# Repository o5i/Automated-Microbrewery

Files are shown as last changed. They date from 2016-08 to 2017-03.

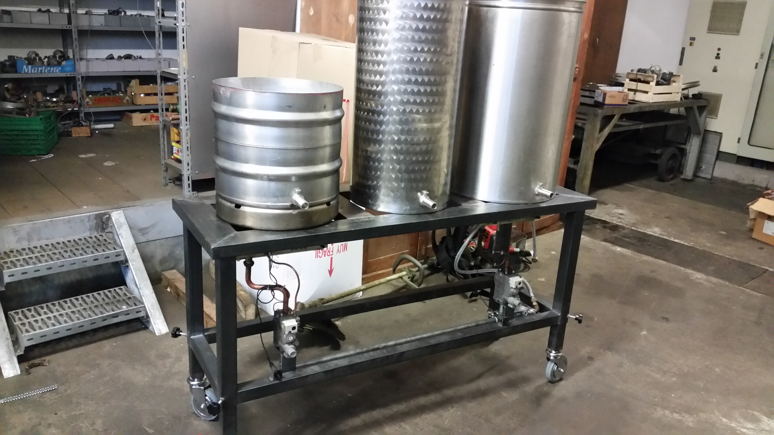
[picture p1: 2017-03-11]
Pics/20160808_192818.jpg

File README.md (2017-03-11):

# Automated-Microbrewery

This is a small hobby/micro brewery based on herms system. i have created for friends.
The setup appart of the work i spend has a good price/quality value. 
In all i spent about 800€ for the hardware.
The controller is made of a raspberry pi (debian linux) interfaced whit a Teensy (Arduino based Microcontroller). 
The program runs on codesys, codesys is a  IEC 61131-3 runtime that allows me to use standard plc programing languages. 
I decided to use the pi because it is possible to interface whit a lot of cheap hardware like the multitouch screen.
The other point is that you have access to the network/internet and you can implement a webinterface or other remote management.
The controller box is made from lasercutted wood.
The gas burners came from old wrecked gas heaters.

Here you can see the controler in action:

https://www.youtube.com/watch?v=9Vse3HxLSbY

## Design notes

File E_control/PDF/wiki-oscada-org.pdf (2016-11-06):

Українська? (http://wiki.oscada.org/HomePageUk/Doc/VCAEngine/edit?add=1)
Русская (http://wiki.oscada.org/Doc/VCAEngine?v=1d1y)

OpenSCADAWiki: Home Page En/ (http://wiki.oscada.org/HomePageEn?v=80q)Doc/VCA (http://wiki.oscada.org/HomePageEn/Doc?v=gns) Engine ... (http://wiki.oscada.org/TextSearch?phrase=HomePageEn%2FDoc%2FVCAEngine)

Home (http://wiki.oscada.org/Home) | Index (http://wiki.oscada.org/PageIndex?v=imj) | Changes (http://wiki.oscada.org/RecentChanges?v=imj) | Comments (http://wiki.oscada.org/RecentlyCommented?v=imj) | Users (http://wiki.oscada.org/Users?v=imj) | Registration (http://wiki.oscada.org/Registration?v=imj) | Login: | Password:

# Module "VCAEngine" of the subsystem "User Interfaces"

Module: | VCAEngine
Name: | Visual control area engine
Type: | User Interfaces
Source: | ui_VCAEngine.so
Version: | 3.7.0
Author: | Roman Savochenko, Maxim Lysenko (2011-2012)
Description: | The main visual control area engine.
License: | GPL

Contents

Introduction

### 1. Purpose 2. The configuration and the formation of interfaces of the VCA 3. Architecture

3.1. Frames and elements of visualization (widgets)
3.2. Project
3.3. Session of the project execution
3.4. Styles
3.5. Events, their processing and the events' maps
3.6. Signaling (Alarms)
3.7. Rights management
3.8. Linkage with the dynamics
3.9. The primitives of the widget Elementary graphic figures (ElFigure)
Element of the form (FormEl)
Text element (Text)
Element of visualization of media materials (Media)
Element of constructing diagrams/trends (Diagram)
Element of building the protocols based on the archives of messages (Protocol) Element of formation of documentation (Document)
Container (Box)
3.10. Database using to store libraries of widgets and projects
3.11. API of the user programming and service interfaces of the OpenSCADA API of the user programming
Service interfaces of OpenSCADA
Access to the values of attributes of the visualization elements (widgets)
Group access to the values of the attributes of the visualization elements (widgets) Access to the pages of the session
Signaling (alarm) management
Manipulation with the sessions of the projects
Group request for the tree of widget libraries

### 4. Configuring the module via the control interface of OpenSCADA

## Introduction

The VCAEngine module provides visual control area engine (VCA) in OpenSCADA system. The module same does not implement the visualization of the VCA, and contains data in accordance with the ideology of "Model/data — Interface". Data visualization of that module is implemented by the visualization modules of VCA, such as Vision (http://wiki.oscada.org/HomePageEn/Doc/Vision?v=1b02) and WebVision. (http://wiki.oscada.org/HomePageEn/Doc/WebVision?v=1e4a)

Visual control area (VCA) is an integral part of the SCADA system. It applies to the client stations with a view to providing accessible information about the object and to for the the issuance of the control actions to the object. In various practical situations and conditions the VCA based on different principles of visualization may by applied. For example, this may be the library of widgets Qt, GTK+, WxWidgets or hypertext mechanisms based technologies HTML, XHTML, XML, CSS, and JavaScript, or third-party applications of visualization, realized in various programming languages Java, Python, etc. Any of these principles has its advantages and disadvantages, the combination of which could become an insurmountable obstacle to the use of VCA in a practical case. For example, technologies like the Qt library can create highly-reactive VCA, which will undoubtedly important for the operator station for control of technological processes (TP). However, the need for installation of that client software in some cases may make using of it impossible. On the other hand, Web-technology does not require installation on client systems and is extremely multi-platform (it is enough to create a link to the Web-server at any Web-browser) that is most important for various engineering and administrative stations, but the responsiveness and reliability of such interfaces is lower that actually eliminates the using of them at the operator of the TP stations.

OpenSCADA system has extremely flexible architecture that allows you to create external interfaces, including user and in any manner and for any taste. For example, the system configuration OpenSCADA as now available as by means of the Qt library, and also the Web-based.

At the same time creation of an independent implementation of the VCA in different basis may cause the inability to use the configuration of one VCA into another one. That is inconvenient and limited from the user side, as well as costly in terms of implementation and follow-up support. In order to avoid these problems, as well as to create as soon as possible the full spectrum of different types of VCA project of the creation of the conception of the VCA (http://wiki.oscada.org/Doc/KoncepcijaSredyVizualizacii?v=ohk) is established. The result of this project — the engine module(data model) of the VCA, as well as direct visualization modules Vision (http://wiki.oscada.org/HomePageEn/Doc/Vision?v=1b02) and WebVision. (http://wiki.oscada.org/HomePageEn/Doc/WebVision?v=1e4a)

## 1. Purpose

This module of the engine (data model) of the VCA is aimed to create the logical structure of the VCA and the execution of sessions of individual instances of the VCA projects. Also, the module provides all the necessary data to the final visualizers of the VCA, both through local mechanisms of interaction of OpenSCADA, and through the management Interface of OpenSCADA for remote access.

The final version of the VCA module will provide:
three levels of complexity in the formation of visualization interface which let organically to develop and apply the tools of the methodology from simple to complex:
1. formation from the template frames through the appointment of the dynamics (without the graphical configuration);

converted by Web2PDFConvert.com

2. graphical formation of new frames through the use of already made visualization elements from the library (mimic panel);
3. formation of new frames, template frames of the visualization elements in the libraries.
building of the visualization interfaces of various complexity, ranging from simple flat interfaces of the monitoring and finishing with the full-fledged hierarchical interface used in SCADA systems;
providing of the different ways of formation and configuration of the user interface, based on different graphical interfaces (Qt, Web, Java ...) and also through the standard management interface of OpenSCADA system;
change of dynamics in the process of execution;
building of the new template frames on the user level and the formation of the frames libraries, specialized for the area of application (eg. the inclusion of frames of parameters, graphs and other items linking them to each other) in accordance with the theory of secondary using and accumulation;
building of the new user elements of the visualization and the formation of the libraries of frames, specialized for the area of application in accordance with the theory of secondary using and accumulation;
description of the logic of new template frames and user visualization elements as with the simple links, and also with the laconic, a full-featured programming language;
the possibility of the inclusion of the functions (or frames of computing of the functions) of the object model of OpenSCADA to the user elements of the visualization, actually linking the presentation of the algorithm of computing (for example, by visualizing the library of models of devices of TP for following visual modeling TP);
separation of user interfaces and interfaces of visualization of data provides building the user interface in a single environment, and performance of it in many others (Qt, Web, Java ...);
the possibility to connect to the performing interface for monitoring and corrective actions (for example, while operator training and control in real time for his actions);
visual building of various schemes with the superposition of the logical links and the subsequent centralized execution in the background (visual construction and performance of mathematical models, logic circuits, relay circuits and other proceedings);
providing of the functions of the object API to the OpenSCADA system, it can be used to control the properties of the visualization interface from the user procedures;
building of the servers of frames, of elements of the visualization and of the project of the interfaces of the visualization with the possibility to serve the set number of the client connections;
simple organization of client stations in different basis (Qt, Web, Java ...) with the connection to the central server;
full mechanism of separation of privileges between the users which allows to create and execute projects with the various rights of access to its components;
adaptive formation of alarms and notifications, with the support of arbitrary ways of notification;
support of the user formation of the palettes and font preferences, into styles, for the visualization of the interfaces;
support of the user formation of maps of the events under the various items of equipment management and user preferences;
support for user profiles, allowing to define various properties of the visualization interface (colors, font characteristics - styles, the preferred maps of events);
flexible storage and distribution of libraries of widgets, frames, and projects of the visualization interfaces in the databases, supported by OpenSCADA; actually users need only to register the database with data.

## 2. The configuration and the formation of interfaces of the VCA

Module itself does not contain mechanisms for visual creating interfaces of VCA, such tools can be given by the final visualization modules of the VCA, for example such a tool provides by the module Vision. (http://wiki.oscada.org/HomePageEn/Doc/Vision?v=1b02)

Although the mechanisms for the visual formation of the VCA the module doesn't provide the interface, implemented on the basis of the management interface of the OpenSCADA, to manage the logical structure is provided, and thus it is available for use in any system configurator of the OpenSCADA. Dialogues of this interface are considered further in the context of the architecture of the module and its data.

## 3. Architecture

/Home Page En / Doc / VC Aconcept / part 4 / part 2 (http://wiki.oscada.org/HomePageEn/Doc/VCAconcept/part4/part2?v=1d34) :: (edit) (http://wiki.oscada.org/HomePageEn/Doc/VCAconcept/part4/part2/edit)

Any VCA can operate in two modes — the development and running. In the development mode the VCA interface and its components are formed, the mechanisms of interaction are identified. While the running it is carried out the formation of VCA interface based on the developed VCA with the final

user interaction is made.

VCA interface is formed of the frames, each of which, in its turn, formed from elements of the primitives, or user interface elements. In doing so, the user interface elements are also formed from the primitives or other user elements. That gives us a hierarchy and reuse of already developed components.

Frames and user elements are placed in the libraries of widgets. The projects of the interfaces of the final visualization of the VCA are formed from these libraries' elements. Based on these projects the visualization sessions are formed.

The structure of VCA is shown in Fig. 3.

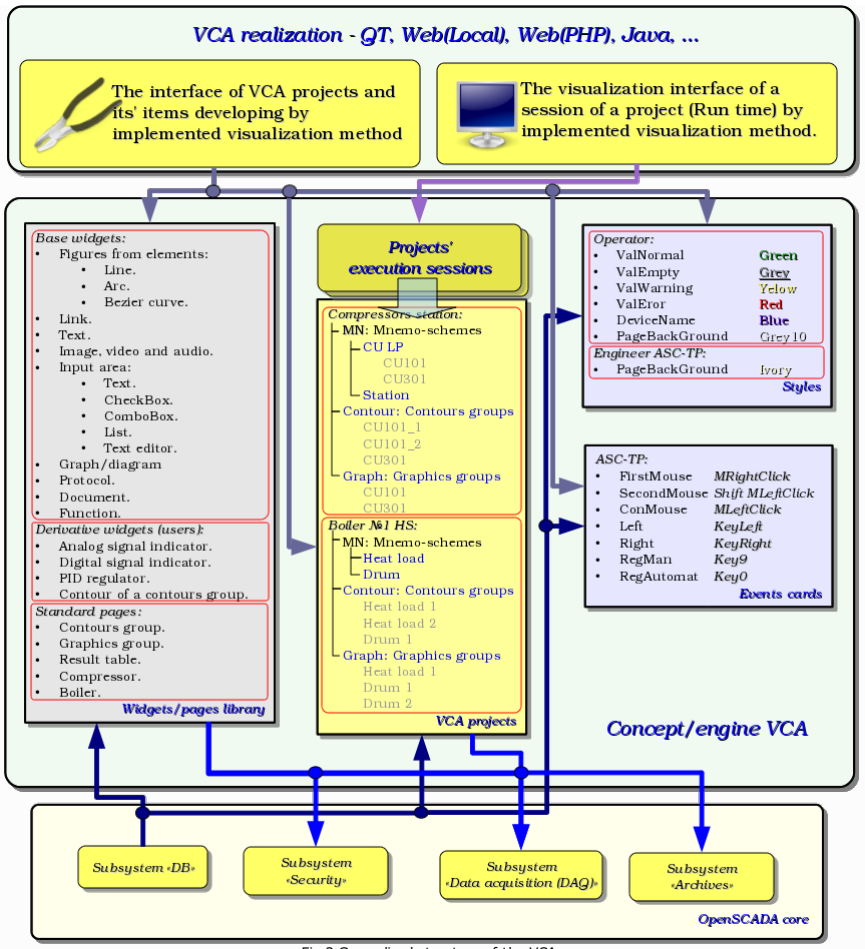
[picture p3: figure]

Fig.3 Generalized structure of the VCA.

This architecture of the VCA allows the support of three levels of complexity of the developing process of the management interface:
Forming of the VC interface (visualization and control) using the library of template frames by placing the templates of the frames in the project and by the assignment of the dynamics.
In addition to the first level the own creation of frames based on the library of derivatives and basic widgets is to be done. Perhaps as a direct appointment of the dynamics in the widget, and the subsequent appointment of it in the project.
In addition to the second level is performed the independently forming of derivatives widgets, new template frames and also the frames with the use of mechanism of describing the logic of interaction and handling of events in one of the languages of a user programming of OpenSCADA system.
/Home Page En / Doc / VC Aconcept / part 4 / part 2 (http://wiki.oscada.org/HomePageEn/Doc/VCAconcept/part4/part2?v=1d34) :: (edit) (http://wiki.oscada.org/HomePageEn/Doc/VCAconcept/part4/part2/edit)

## 3.1. Frames and elements of visualization (widgets)

/Home Page En / Doc / VC Aconcept / part 4 / part 3 (http://wiki.oscada.org/HomePageEn/Doc/VCAconcept/part4/part3?v=k3m) :: (edit) (http://wiki.oscada.org/HomePageEn/Doc/VCAconcept/part4/part3/edit)
Frame is the window which directly provides information to the user in a graphical or text form. The group of interconnected frames creates whole user interface of VC.

Contents of the frame is forming from the elements of visualization (widgets). Widgets may be the basic primitives (different elementary shapes, text, trend, etc.) and derivatives (formed from the basic or other derivatives of widgets). All the widgets are grouped into the libraries. In the process, you can build your own library of derivative widgets.

Actually the frame is also a widget that is used as a final element of visualization. This means that the widget libraries can store the blanks of frames and the templates of the resulting pages of the user interface.

Frames and widgets are passive elements that do not normally contain links to the dynamics and other frames, but only provide information about the properties of the widget and the nature of the dynamics (configuration), connected to the properties of the frame. Activated frames, ie containing links to the dynamics and active connections, form the user interface and are stored in the projects. In some cases, it is possible the direct appointment of the dynamics in the blanks of frames.

Derivative frames/widgets can contain other widgets (attached), which can be glued (associated) with the logic of one another by one of the languages of programming available in the OpenSCADA system.

The widget is an element, by means of which it is provided:
visualization of operational and archive information about TP;
alarm about a violation of conduction of TP;
switching between the frames of TP; management of technological equipment and the parameters of conduction of TP.

Tuning and linkage of the widgets is done through their properties. Parent widget and the widgets it contains, can be complemented by user properties. Then the user and static attributes are associated with the properties of embedded widget by internal logic. To show the dynamics (ie, current and archived data), properties of widgets are dynamized, that is linked with the attributes of the parameters of OpenSCADA or properties of other widgets. Using to link of the nested widgets by means of the internal logic with the available programming language of the OpenSCADA system eliminates the question of the implementation of complex logic of visualization, thus providing high flexibility. Practically, you can create fully dynamized frames with complex interactions at the level of the user.
/Home Page En / Doc / VC Aconcept / part 4 / part 3 (http://wiki.oscada.org/HomePageEn/Doc/VCAconcept/part4/part3?v=k3m) :: (edit) (http://wiki.oscada.org/HomePageEn/Doc/VCAconcept/part4/part3/edit)

## 3.2. Project

/Home Page En / Doc / VC Aconcept / part 4 / part 4 (http://wiki.oscada.org/HomePageEn/Doc/VCAconcept/part4/part4?v=oor) :: (edit) (http://wiki.oscada.org/HomePageEn/Doc/VCAconcept/part4/part4/edit)
Direct configuration and properties of the final visualization interface are contained in the project of the visualization interface of the VCA, which may be created lot ones.

Each project includes pages from the libraries of the frames/widgets. In some modes the page allowed to include into nested pages as independent from the parent and in using the parent as template. The template's page-widget allows to extremely simplify the process of creating the same type of the frames by the ACS-TP engineer or by the user of OpenSCADA for easy monitoring. An example of such one-type frames may be: groups of contours, groups of graphs, reports and various tables. Mnemonic schemes of technological processes rarely come under this scheme and will be formed directly in the description of the frame.

Page like to a widget on which it is based provides a possibility for bind the dynamics to described into properties, which links at all can be set to dynamic or resolved as constants. Besides, links to the dynamics on the project's page level is preferable to the widget of libraries level.

Example of hierarchical representations of components of the project of the classical interface of VC of the technological process with the description of standard call expressions is given in Figure.

Reserved next the special properties of pages:
Container — page is a container for the underlying pages.
Template — page is a template for the underlying pages.
Empty — empty and inactive page. This property is used in conjunction with the property Container for logical containers organization.

Based on these properties combinations the following types of pages are realized:
Standard — the standard page (none property is set), it is the full final page.
Container — the full-featured page with the property of the container (Container).
Logical container — the logical container is actually not a page (Container|Empty), but it performs property of the intermediate and bunching element in the tree of pages.
Template — the template page (Template). Pure template page is used to describe the common properties and expand them definitions in privately order in nested pages.
Container and template — the template and a container page (Template|Container), combines the functions of the template and the container.

On the side of the visualization (RunTime), on the following attributes of the basic element "Box", there is the logic regulating how to open the pages: pgOpen — sign "The page is opened";
pgNoOpenProc — sign "Execute the page, even if it is not opened";
pgOpenSrc — contains the address of the widget or of the page which has opened the current; in the case of the nested container widget here it is contained the address of the included page; to open the pages from the script here it is enough to indicate the address of the widget-source of the opening;
pgGrp — group of pages, used for conjunction of the containers of the pages with the pages in accordance with the general group.

The logic of the method of the opening the pages works in the following way:
if the page has the group "main" or coincides with a group of the page in the main window or there is no page on the main window, then open the page in the main window;
if the page has a group which coincides with the group one of the containers of the current page, then open it in the container;
if the source of the opening of the page coincides with the current page, then open it as an additional window over the current page;
transmit a call for request for the opening to the additional windows with the processing in each of the first three paragraphs;
if any one of the relative windows doesn't open a new page, then open it as a related window of the main window.
/Home Page En / Doc / VC Aconcept / part 4 / part 4 (http://wiki.oscada.org/HomePageEn/Doc/VCAconcept/part4/part4?v=oor) :: (edit) (http://wiki.oscada.org/HomePageEn/Doc/VCAconcept/part4/part4/edit)

## 3.3. Session of the project execution

/Home Page En / Doc / VC Aconcept / part 4 / part 5 (http://wiki.oscada.org/HomePageEn/Doc/VCAconcept/part4/part5?v=5ox) :: (edit) (http://wiki.oscada.org/HomePageEn/Doc/VCAconcept/part4/part5/edit)
The project's session is expanded tree of the project for direct it execution, which includes an individual task of hierarchical the widget's procedures execution. For each project can be opened many sessions. The end-user visual interface forming performs by the visualizers from data of the project's session, after the session creation by the request.

Between widgets at the different levels of hierarchy complex inheritance relations are arranged, which are defined by the possibility of using some widgets by other ones, beginning with the library widget, and finishing with the widget to the session. To clarify these features of the interaction in Figure comprehensive map of "uses" inheritance is shown.

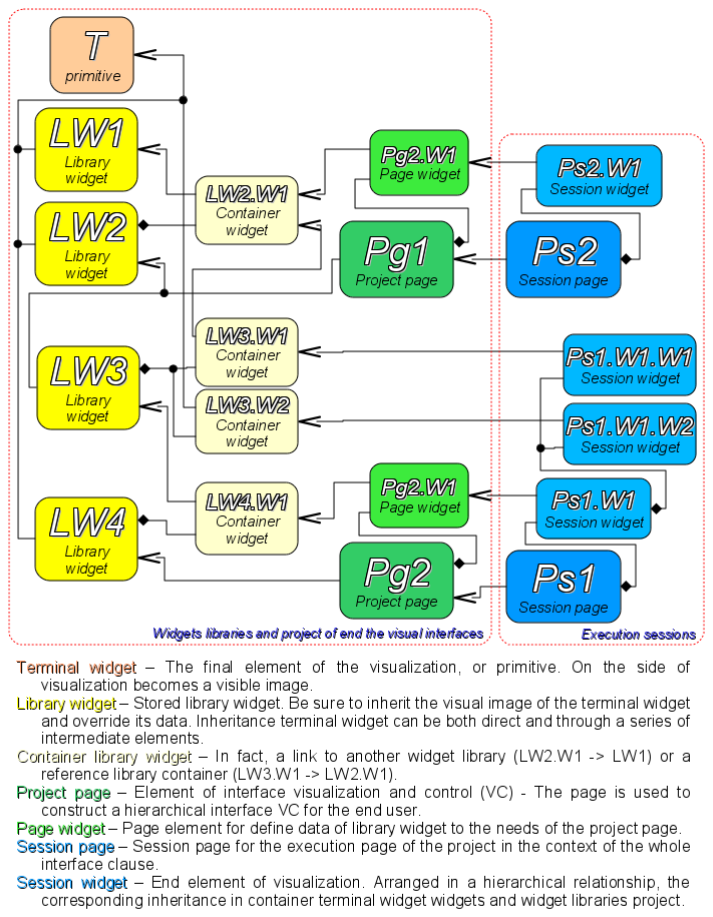
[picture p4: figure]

At the session level widget contains a object of values of calculation procedure. This object is initiated and used in the case of presence of the calculation procedure. At the time of the initialization the list of parameters of the procedure is created and a compilation of procedure is performed with these parameters in the module, implementing the selected programming language and encoded with the full name of the widget. A compiled function is connected to the object of values of the calculation procedure. Further the calculation is performed with the frequency of the session.

Calculation and processing of the widget on the whole runs in the following sequence:
the events, which are available at the time of computation, are selected from the attribute "event" of the widget;
events are loaded into the parameter "event" of the object of computation;
values of the input connections are loaded into the object of calculation;
values of special variables are loaded into the computation object (f_frq, f_start and f_stop);
values of selected parameters of the widget are loaded into the object of computation; computation;
uploading of the computation object's values to the selected parameters of the widget; uploading of the event from the parameter "event" of the computation object;
processing the events and transfer the unprocessed events at the level above.

The objects of the session of the project inherit from an abstract object "Widget" and use the appropriate objects of the project. Thus, the session ("Session") uses the project ("Project") and forms expand tree on its basis. Project page "Page" is directly used by the session page "SessPage". The remaining objects ("SessWdg") are deployed in accordance with the hierarchy of page elements (Fig.3.1.2).

In addition to the standard properties of an abstract widget ("Widget") elements of the pages of session themselves get the following properties: (http://www.web2pdfconvert.com?ref=PDF)

storage of the object of values of computational procedure, calculation of the procedures and mechanism for processing of the events. Pages of the session, in addition, contain a container of the following by the hierarchy pages. The session generally is computed with the frequency and in the consistency:
"Page of the top level" -> "Page of the lower level"
"Widget of the lower level" -> "Widget of the top level"

This policy allows you to circumvention the pages in accordance with the hierarchy, and to rise on the top during the one iteration for the widget events.
/Home Page En / Doc / VC Aconcept / part 4 / part 5 (http://wiki.oscada.org/HomePageEn/Doc/VCAconcept/part4/part5?v=5ox) :: (edit) (http://wiki.oscada.org/HomePageEn/Doc/VCAconcept/part4/part5/edit)

## 3.4. Styles

/Home Page En / Doc / VC Aconcept / part 4 / part 6 (http://wiki.oscada.org/HomePageEn/Doc/VCAconcept/part4/part6?v=6si) :: (edit) (http://wiki.oscada.org/HomePageEn/Doc/VCAconcept/part4/part6/edit)
It knows that people can have individual characteristics in the perception of graphical information. If these features are not taken into account, it is possible to obtain the rejection and abruption of the user to the interface of VC. This rejection and abruption can lead to fatal errors in the management of TP, as well as traumatize the human by the continuous work with the interface. In SCADA systems the agreements are adopted, which regulate the requirements for creating a unified interface of VC normally perceived by most people. This is practically eliminates the features of people with some deviations.

In order to take this into account and allow centralized and easy to change the visual properties of the interface module is implementing a theme manager of the visualization interface.

User can create many themes, each of which will keep the color, font and other properties of the elements of the frame. Simple changing of the theme will allow you to change the interface of VC, and the possibility of appointing an individual theme in the user's profile allows to take into account his individual characteristics.

To realize this opportunity, when you create a frame, it is necessary for the properties of color, font and others set the "Config" (of the table in the "Process" tab) in the value of "From style". And in the parameter "Config template" to specify the identifier of the style field. Further, this field will automatically appear in the Style Manager and will be there to change. Style Manager is available on the project configuration page in the tab "Styles". On this tab you can create new styles, delete old ones, change the field of the style and delete unnecessary.

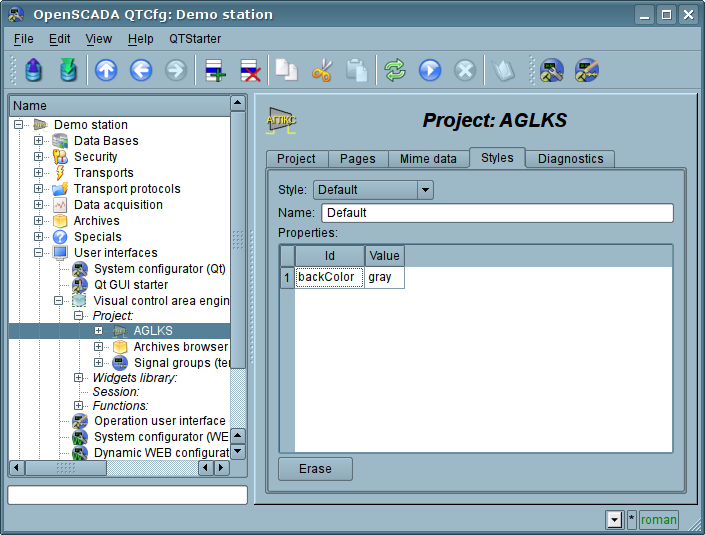
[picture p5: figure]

Figure. "Styles" tab of the configuration page of the project.

In general the styles are available from the project level. At the level of libraries of widgets you can only define styles fields of widgets. At the project level, at the choice of style, it is started the work with styles, which includes access to the fields of styles instead of direct attribute values. In fact, this means that when reading or writing a widget attribute these operations will be carried out with the corresponding field of the chosen style.

When you run the project execution it will be used the set in the project style. Subsequently, the user can select a style from the list of available ones. The user's style will be saved and used next time you run the project.
/Home Page En / Doc / VC Aconcept / part 4 / part 6 (http://wiki.oscada.org/HomePageEn/Doc/VCAconcept/part4/part6?v=6si) :: (edit) (http://wiki.oscada.org/HomePageEn/Doc/VCAconcept/part4/part6/edit)

## 3.5. Events, their processing and the events' maps

/Home Page En / Doc / VC Aconcept / part 4 / part 7 (http://wiki.oscada.org/HomePageEn/Doc/VCAconcept/part4/part7?v=12be) :: (edit) (http://wiki.oscada.org/HomePageEn/Doc/VCAconcept/part4/part7/edit)
Given the range of tasks for which the OpenSCADA system may be used, it is necessary to provide a tool for management of interactive user events. This is due to the fact that in dealing with individual tasks of embedded systems, input and control devices can greatly vary. But it is enough to look at the regular office keyboard and notebook one, that would remove any doubt about the necessity for the manager of events.

The events manager must work using the maps of events. Map of the events — is the list of named events, indicating their origin. The origin of the events can be a keyboard, mouse, paddle, joystick, etc. At an event emerge the events manager is looking for it in the active map and compares with the name of the event. A comparison name of the event is placed in the queue for processing. Widgets in this case must process the given queue of events.

The active map of events is specified in the profile of each user or it is set by default (in planes).

In general, four types of events are provided:
events of the shapes-primitives of VCA (prefix: ws_), for example, pressing of the display button event — "ws_BtPress"; keyboard events (prefix: key_) — all events from mouse and keyboard in the form of — "key_presAlt1";

user events (prefix: usr_) are generated by the user in the procedures of the calculation of widgets; mapping of the event (prefix: map_) — events from the map of events, in planes.

Event itself represents deficiently information, especially if its processing occurs at higher level. For the unequivocal identification of the event and its source in the whole the event is recorded as follows: "ws_BtPress:/curtime". Where:
ws_BtPress — same event;
/curtime — the path to the child element that has generated the event.

Table 3.5 provides a list of standard events, the support of which should be provided in visualizers of VCA.

Table 3.5. Standard events
Id | Description

Keyboard events: key_[pres|rels][Ctrl|Alt|Shift]{Key}

*SC#3b | Scan-code of the key.
*#2cd5 | Code of the unnamed key.
*Esc | "Esc".
*BackSpace | Removing of the previous character — "<--".
*Return, *Enter | Enter — "Enter".
*Insert | Insertion — "Insert".
*Delete | Deleting — "Delete".
*Pause | Pause — "Pause".
*Print | Print of the screen — "Print Screen".
*Home | Home — "Home".
*End | End — "End".
*Left | Left — "<-".
*Up | Up — '^'.
*Right | Right — "->".
*Down | Down — '\/'.
*PageUp | Page up — "PageUp".
*PageDown | Page down — "PageDown".
*F1 ... *F35 | Function key from "F1" to "F35".
*Space | Space — ' '.
*Apostrophe | Apostrophe — '`'.
*Asterisk | Asterisk on an additional field of the keyboard — '*'.
*Plus | Plus on an additional field of the keyboard — '+'.
*Comma | Comma — ','.
*Minus | Minus — '-'.
*Period | Period — '.'.
*Slash | Slash — '\'.
*0 ... *9 | Number from '0' to '9'.
*Semicolon | Semicolon — ';'.
*Equal | Equal — '='.
*A ... *Z | Keys of Latin alphabet from 'A' to 'Z'.
*BracketLeft | Left square bracket - '['.
*BackSlash | Backslash — '/'.
*BracketRight | Right square bracket — ']'.
*QuoteLeft | Left quote — '''.

Keyboard focus events.

ws_FocusIn | Focus is obtained by a widget.
ws_FocusOut | Focus is lost by a widget.

Mouse events:

key_mouse[Pres|Rels][Left|Right|Midle] | Pressed/released the mouse button.
key_mouseDblClick | Double-click the left mouse button.

Events of quittance on the side of the visualizer.

ws_alarmLev | Quittance of all violations by all notices methods and types.
ws_alarmNtf{N} | Quittance of all violations by the type {N} (0...7).

Events of the primitive of elemental figure ElFigure:

ws_Fig[Left|Right|Midle|DblClick] | Activating of the figures (fills) by the mouse button.
ws_Fig{N}[Left|Right|Midle|DblClick] | Activating of the figure (fill) N by the mouse button.

Events of the primitive of form elements FormEl:

ws_LnAccept | A new value in the input line is set.
ws_TxtAccept | The value of the text editor is changed.
ws_ChkChange | The state of the flag is changed.

ws_BtPress | The button is pressed.
ws_BtRelease | The button is released.
ws_BtToggleChange | The button toggle is changed.
ws_BtMenu={Item} | Selection of the menu Item.
ws_BtLoad | The selected file loaded.
ws_CombChange | The value of the combo box is changed.
ws_ListChange | The current list item is changed.
ws_TreeChange | The current tree item is changed.
ws_TableChangeSel | The table's item selection changed.
ws_TableEdit_{colN}_{rowN} | The table's cell ({colN}:{rowN}) edited.
ws_SliderChange | The slider position changed.

Events of the primitive of media content Media:

ws_MapAct{N}[Left|Right|Midle] | Media area with the number N is activated by the mouse button.
ws_MediaFinished | Media-stream play is finished.

Events are the main mechanism of notification and is actively used for user interaction. For the event processing there are two mechanisms: Primary — the script uses to control the opening of the pages.
Secondary — the computational procedure of the widget.

The mechanism "Scripts for the control the opening of pages" based on the basic attribute of the widget "evProc", which can be used for switching, opening, substitution and navigation through the pages. The scenario of this attribute is stored as a list of commands with the syntax: "{event}: {evSrc}:{com}:{prm}". Where:
event — the expected event;
evSrc — the path of the nested widget-source of the event;
com — the session command;
prm — the parameter of the command.

The following commands are implemented:
open — opening page; page to open is specified in the parameter prm both in direct way and as a template (example: /pg_so/1/*/*); next — opening of the next page; page to open is specified in the parameter prm as a template (example: /pg_so/*/*/$);
prev — opening of the previous page; page to open is specified in the parameter prm as a template (example: /pg_so/*/*/$).

Special characters of the template are deciphered as follows:
pg_so — direct name of the desired-static page (with the prefix), requires the compulsory accordance and is used to identify the last open page; 1 — name of a new page in a general way (without a prefix);
* — the page is taken from the name of a previous opened page or the first available page is substituted, if the previous opened page is missing; $ — points the place of the opened page relative to which you are to go to the next or to the previous one.

To more and true the mechanism of the templates understanding lets cite some real examples:
Changing the signal object:
Initially: /pg_so/pg_1/pg_mn/pg_1 Command: open:/pg_so/2/*/* Result: /pg_so/pg_2/pg_mn/pg_1 Switching of the type:
Initially: /pg_so/pg_1/pg_mn/pg_1 Command: open:/pg_so/*/gkadr/* Result: /pg_so/pg_1/pg_gkadr/pg_1 Next/previous page of the type: Initially: /pg_so/pg_1/pg_mn/pg_1 Command: next:/pg_so/*/*/$ Result: /pg_so/pg_1/pg_mn/pg_2

As an example lets cite the scenario of operation of the main page of the user interface:

ws_BtPress:/prev:prev:/pg_so/*/*/$
ws_BtPress:/next:next:/pg_so/*/*/$
ws_BtPress:/go_mn:open:/pg_so/*/mn/* ws_BtPress:/go_graph:open:/pg_so/*/ggraph/* ws_BtPress:/go_cadr:open:/pg_so/*/gcadr/* ws_BtPress:/go_view:open:/pg_so/*/gview/* ws_BtPress:/go_doc:open:/pg_so/*/doc/* ws_BtPress:/go_resg:open:/pg_so/rg/rg/* ws_BtPress:/so1:open:/pg_so/1/*/* ws_BtPress:/so2:open:/pg_so/2/*/* ws_BtPress:/so3:open:/pg_so/3/*/* ws_BtPress:/so4:open:/pg_so/4/*/* ws_BtPress:/so5:open:/pg_so/5/*/* ws_BtPress:/so6:open:/pg_so/6/*/* ws_BtPress:/so7:open:/pg_so/7/*/* ws_BtPress:/so8:open:/pg_so/8/*/* ws_BtPress:/so9:open:/pg_so/9/*/* ws_BtPress:*:open:/pg_control/pg_terminator

The mechanism "Processing the events with the help of computational procedure of the widget" is based on the attribute "event" and the user procedure of calculating written with the help of the programming language of OpenSCADA. The events, in process of receipt, are accumulated in the attribute "event" till the moment of call of the computational procedure. The computational procedure is called with the specified frequency of calculating the widget and receives a value for the attribute "event" as the list of events. In the calculation procedure the user can: analyze, process and delete the processed events from the list, and add to the list new events. The remaining, after the procedure execution, and new events are analyzed for compliance with the conditions of the call by means of script of the primary mechanism, after which the remaining events are transmitted to the upper by the hierarchy widget to be processed by it, with the correction of the path of events in accordance with the hierarchy of the penetration of the event.

The content of the attribute "event" is a list of events in the format "{event}:{evSrc}", with the event on the separate line. Here is an example of (http://www.web2pdfconvert.com?ref=PDF) processing events in the Java-like programming language of the OpenSCADA:

for(ev_rez = "", off = 0; (sval=event.parse(0,"\n",off)).length; ) { if(sval == "ws_BtPress:/cvt_light") alarmSt = 0x1000001;
else if(sval == "ws_BtPress:/cvt_alarm") alarmSt = 0x1000002; else if(sval == "ws_BtPress:/cvt_sound") alarmSt = 0x1000004; else ev_rez += sval+"\n";
}
event = ev_rez;

/Home Page En / Doc / VC Aconcept / part 4 / part 7 (http://wiki.oscada.org/HomePageEn/Doc/VCAconcept/part4/part7?v=12be) :: (edit) (http://wiki.oscada.org/HomePageEn/Doc/VCAconcept/part4/part7/edit)

## 3.6. Signaling (Alarms)

/Home Page En / Doc / VC Aconcept / part 4 / part 8 (http://wiki.oscada.org/HomePageEn/Doc/VCAconcept/part4/part8?v=klz) :: (edit) (http://wiki.oscada.org/HomePageEn/Doc/VCAconcept/part4/part8/edit)
An important element of any visualization interface is the user notification about the violation — alarming. To simplify the perception, but also in mind the close connectivity of visualization and notification (typically notification is amplified with the visualization) it is decided to integrate the interface of a notification in the visualization interface. To do this, all the widget provides two additional attributes (of the session level): "alarm" and "alarmSt". Attribute "alarm" is used to form the signal by the widget, according to his logic, and attribute "alarmSt" is used to control the signaling fact of the branch of the tree of the session of the project.

Attribute "alarm" is a line and has the following format: "{lev}|{categ}|{message}|{type}|{tp_arg}" Where:

lev — signaling (alarm) level; number from 0 to 255;
categ — alarm category; parameter of the acquisition subsystem, object, path, or their combination; message — signaling (alarm) message;

type — type of notification, is formed as a the integer number (0...7), which contains the flags of notification methods; typical notification methods:

1 — visual;
2 — beep tone, is frequently made through the PC-speaker;
4 — sound signal from the sound file or the speech synthesis, and if in the tp_arg the name of the resource of the sound file is specified, then play it, or in other case the speech synthesis from the text specified in message is made.
tp_arg — argument of the type; it is used in the case of the audible signal to indicate the resource of the sound alarm (file of the sound format).

Attribute "alarmSt" is an integer number that represents the maximum alarm level and the fact of the quittance of the branch of the tree of the session of the project. Format of the number is as follows:
first bite (0...255) characterizes the level of the alarm of the branch;
the second byte indicates the type of notification (as well as in the attribute "alarm");
the third byte indicates the type of notification without quittance (as well as in the attribute "alarm"); the four byte has special appointment, assigns different bites
bit 0 — indicates, by sets, to quittance fact of notification into first byte;
bit 1 — indicates, by sets it and the bit 0, to the quittance return — enable back the quittance.

Alarm formation and receipt of it by the visualizer.
The alarm formation is performed by the widget by setting its own attribute "alarm" in appropriate way and in accordance with it the attribute "alarmSt" of current and the parent widget is set. Visualizers receive notification of the alarm using a standard mechanism for notifications of the changes of attributes of widgets.

Taking into account that the processing of conditions of the signaling is made in the widgets, the pages containing the objects of signaling should be performed in the background, regardless of their openness to the moment. This is done by setting a flag of the background execution of the page.

Although the mechanism of signaling is built in the visualization area the possibility of formation of visual signaling elements remains, for example by creating the page that will never be opened.

Quittance
Quittance is process of accepting the violation(s) to mind, disabling the notification and action to remove the violation(s). In the display of user's interface the quittance assume only the notification disable.

Quittance performs by specifying the root of the branch of the widgets and the types of notification. This allows to make quittance on the side of visualizer both as by groups, for example by the signaling objects as well as individually by the objects. It is possible to independently quittance different types of alarms. Setting of the quittance is made by the simple modification of the attribute "alarmSt".

Example of the script to work with the signals gives below:

//Secretion of the existence of alarms for different ways of notification
cvt_light_en = alarmSt&0x100; cvt_alarm_en = alarmSt&0x200; cvt_sound_en = alarmSt&0x400; //Secretion of the existence of alarms which not in quittance for different ways notification cvt_light_active = alarmSt&0x10000; cvt_alarm_active = alarmSt&0x20000; cvt_sound_active = alarmSt&0x40000;
//Processing of the button's events of quittance and the quittance for different ways of notification
for(ev_rez = "", off = 0; (sval=event.parse(0,"\n",off)).length; ) {
if(sval == "ws_BtPress:/cvt_light") alarmSt = 0x1000001;
else if(sval == "ws_BtPress:/cvt_alarm") alarmSt = 0x1000002; else if(sval == "ws_BtPress:/cvt_sound") alarmSt = 0x1000004; else ev_rez += sval + "\n";
}

External notification methods
A first and a typical method of notifications is display's light notification by alarm colors and its dynamic about proper visual elements, which always presents and does not require of specific configuration. But often we need for an external type notification, for example: external lamp, PC buzzer or "howler", arbitrary sound, synthesized speech and etc.

For the possibility of implements the external notification methods and the accorded notification types are free described for the visualization server and same visualizers. On the visualization server side describes for forming/getting the notification resource and same notification. On the visualizers side describes a notification by the resources from the visualization server.

The external notifications describes on main page by attributes of text type:

Description of rules and scenarios of notifications performs with user attributes of text type for pages of the visualization project, which applies at the page open. That is potentially for each opening page there possible describe self rules of notifications but typically here enough to describe a generic (http://www.web2pdfconvert.com?ref=PDF) rules of notification on the main project's page, which open once and doesn't close in work:

For the visualization server/engine by the attribute "notify{N}" into the format:

//flags=notify[{DL}][|resource[|queue[|qMergeMess]]];
if(doRes) { The command text to form the resource. }
if(doNtf) { The command text to notify. }

For a visualizer by the attribute "notifyVis[Vision|WebVision]{N}" into the format:

//flags=notify[{DL}][|resource[|queue[|quittanceRet]]]; //name={The notifier name}
//ico={The icon name}
{ The notification command text to any or concrete visualizer. }

Flags:
notify[{DL}] — enables notification with repeat by time DL, if the set; for DL = 0 the repeat made once.
resource — request-form (force) the notification resource from the visualization server, can be an audio file, a text or other data for the notification produce.
queue — the notification resources appoint not only by global alarming sign and the quittance but follow to the priority queue of sources of the notification-resources. The queue forms on the visualization server side and for the visualizers set need of working with it at the resources request.
qMergeMess — merging the notifications into the queue by equality its messages.
quittanceRet — possibility of a visualizer for a quittance recall-return ie in fact the notification enable back.

The exchanging variables:
en[0,1] — the notification enable (1) or disable (0);
doNtf[0,1] — call the script for the notification;
doRes[0,1] — call the script for the resource form;
res — the content or the content's file name (for external scripts) of the resource; mess — the message-parameters for the resource and the notification form.

lang — the language of current user or system.

The examples and comments to work of typical notification methods: Beep (buzzer) on a visualizer or the visualization server side: alarm = "10|Prm||0x02"
notifyVisVision1 | notify1 =

//flags=notify
if(en) SYS.system("beep -f 1000 -l 1000000 &", true);
else if((beepPID=SYS.system("pidof beep")).toInt()) SYS.system("kill "+beepPID);
notifyVisVision1 | notify1 =

#!/bin/sh

#flags=notify

if test $en = 1; then
beep -f 1000 -l 1000000 &
else
beepPID=$(pidof beep)
if test "x$beepPID" != "x"; then kill $beepPID; fi fi

Repeating play for ready audio file, one common, on a visualizer or the visualization server side: alarm = "10|Prm||0x04"
notify2 | notifyVisVision2 =

//flags=notify2
if(en) SYS.system("play -q alarm.ogg");
notify2 | notifyVisVision2 =

#!/bin/sh

#flags=notify2

if test $en = 1; then play -q alarm.ogg; fi

Play an individual audio file for the source, on the visualization server side: alarm = "10|Prm||0x04|res:al_prm1"
notify2 =

//flags=queue

notifyVisVision2 =

//flags=notify2|queue
if(doNtf && en && res.length) { SYS.fileWrite("tmpPlay", res); SYS.system("play -q tmpPlay"); SYS.fileRemove("tmpPlay");
}

notifyVisVision2 =

#!/bin/sh

#flags=notify2|queue

if test $doNtf = 1 -a $en = 1 -a -s $res; then play -q $res; fi

Speech synth for an individual message for the source, on a visualizer side:
alarm = "10|Prm|Text message for the speech synth|0x04"
notify2 =

//flags=queue

notifyVisVision2 =

//flags=notify2|queue
if(doNtf && en && mess.length) { SYS.fileWrite("tmpForSpeech", mess); SYS.system("festival --tts tmpForSpeech"); SYS.fileRemove("tmpForSpeech");
}

notifyVisVision2 =

#!/bin/sh

#flags=notify2|queue

if test $doNtf = 1 -a $en = 1 -a "x" != "x$mess"; then echo $mess > tmpForSpeech
festival --tts tmpForSpeech
rm tmpForSpeech
fi

Once audio file prepare and playing that on a visualizer or the visualization server side:

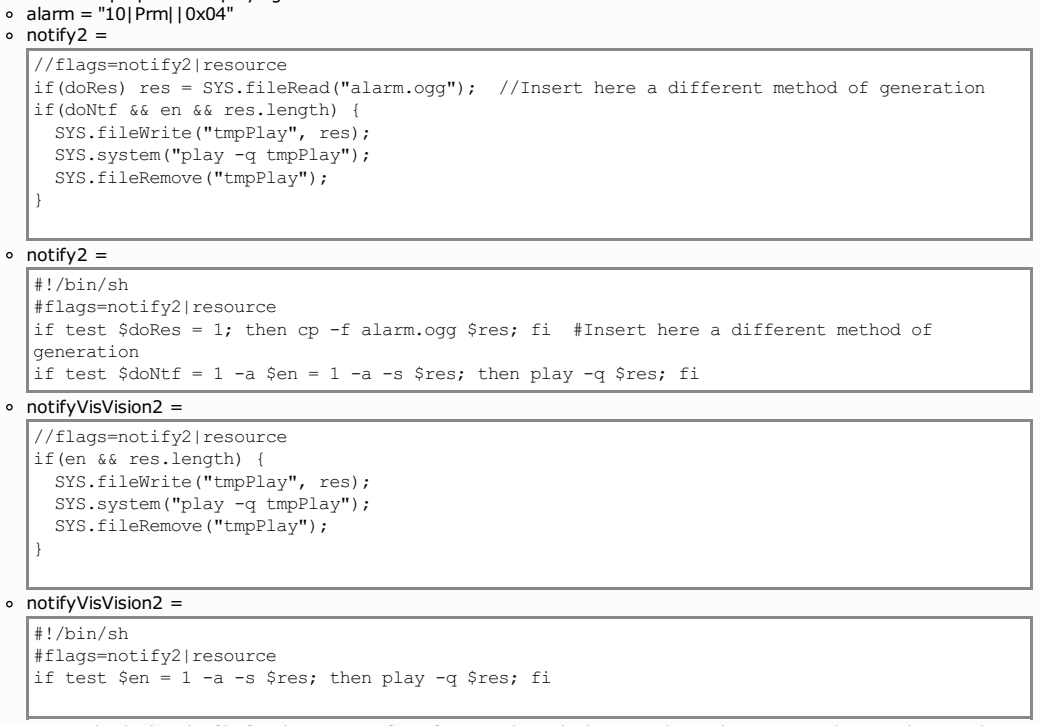
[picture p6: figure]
alarm = "10|Prm||0x04" notify2 =; //flags=notify2|resource; if(doNtf && en && res.length) { SYS.fileWrite("tmpPlay", res);; SYS.system("play -q tmpPlay"); SYS.fileRemove("tmpPlay");; notify2 =; #!/bin/sh; #flags=notify2|resource; generation; notifyVisVision2 =; if(en && res.length) { SYS.fileWrite("tmpPlay", res);

if(doRes) res = SYS.fileRead("alarm.ogg"); | //Insert here a different method of generation
if test $doRes = 1; then cp -f alarm.ogg $res; fi | #Insert here a different method of

if test $doNtf = 1 -a $en = 1 -a -s $res; then play -q $res; fi

if test $en = 1 -a -s $res; then play -q $res; fi

Prepare an individual audio file for the source of notification through the speech synth, on a visualizer or the visualization server side: alarm = "10|Prm|Text message for the speech synth|0x04"

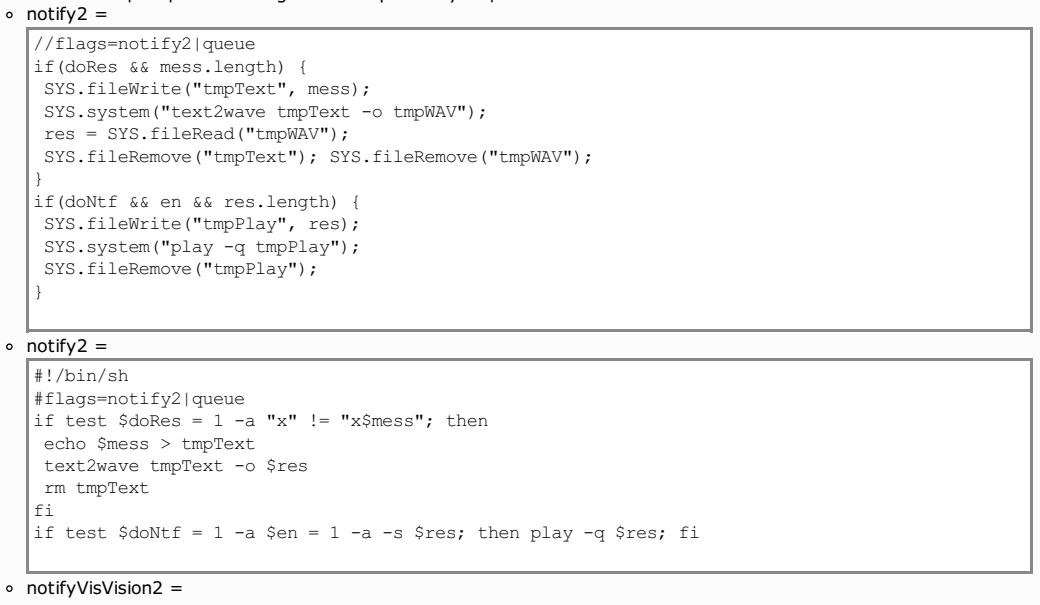
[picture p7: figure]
notify2 =; //flags=notify2|queue; if(doRes && mess.length) { SYS.fileWrite("tmpText", mess);; res = SYS.fileRead("tmpWAV");; } if(doNtf && en && res.length) { SYS.fileWrite("tmpPlay", res);; SYS.system("play -q tmpPlay"); SYS.fileRemove("tmpPlay");; #!/bin/sh; #flags=notify2|queue; echo $mess > tmpText text2wave tmpText -o $res; rm tmpText fi; notifyVisVision2 =

SYS.system("text2wave tmpText -o tmpWAV");

SYS.fileRemove("tmpText"); SYS.fileRemove("tmpWAV");

if test $doRes = 1 -a "x" != "x$mess"; then

if test $doNtf = 1 -a $en = 1 -a -s $res; then play -q $res; fi

//flags=notify2|queue
if(en && res.length) {
SYS.fileWrite("tmpPlay", res); SYS.system("play -q tmpPlay"); SYS.fileRemove("tmpPlay");
}

notifyVisVision2 =

#!/bin/sh

#flags=notify2|queue

if test $en = 1 -a -s $res; then play -q $res; fi

/Home Page En / Doc / VC Aconcept / part 4 / part 8 (http://wiki.oscada.org/HomePageEn/Doc/VCAconcept/part4/part8?v=klz) :: (edit) (http://wiki.oscada.org/HomePageEn/Doc/VCAconcept/part4/part8/edit)

## 3.7. Rights management

/Home Page En / Doc / VC Aconcept / part 4 / part 9 (http://wiki.oscada.org/HomePageEn/Doc/VCAconcept/part4/part9?v=ebr) :: (edit) (http://wiki.oscada.org/HomePageEn/Doc/VCAconcept/part4/part9/edit)
For the separation of access to the interface of VC and its components every widget contains information about the owner, about its group and access rights. Access rights are recorded as is the convention in the OpenSCADA system, in the form of a triad: "{user}{groups}{rest}" where each element consists of three attributes of access. Groups list writes through symbol ','. For the elements of the VCA the following interpretation is taken:
'r' — the right to review the widget;
'w' — the right to control over the widget.

In the development mode a simple scheme of access "root.UI:RWRWR_" is used, which means — all users can open and view the libraries, their components and projects, and all users of group "UI" user interfaces) can edit.

In the running mode the right described in the components of interface work, which provide possibility for inheritance the owner and the permissions from top to bottom. Wherein by default the inheritance enabled for each widget, then they get the owner and the permissions of the project. Into that time, the permissions direct setting will propagate they to all components of the widget.
/Home Page En / Doc / VC Aconcept / part 4 / part 9 (http://wiki.oscada.org/HomePageEn/Doc/VCAconcept/part4/part9?v=ebr) :: (edit) (http://wiki.oscada.org/HomePageEn/Doc/VCAconcept/part4/part9/edit)

## 3.8. Linkage with the dynamics

/Home Page En / Doc / VC Aconcept / part 4 / part 10 (http://wiki.oscada.org/HomePageEn/Doc/VCAconcept/part4/part10?v=541) :: (edit) (http://wiki.oscada.org/HomePageEn/Doc/VCAconcept/part4/part10/edit)
To provide relevant data in the visualization interface the data of subsystems "Data acquisition (DAQ)" must be used. The nature of these data as follows:
1. parameters that contain some number of attributes;
2. attributes of the parameter can provide information of five types: Boolean, Integer, Real, String and Object;
3. attributes of the parameter can have their history (archive);
4. attributes of the parameter can be set to read, write, and with full access.

Considering the first list item it is necessary to allow the possibility of the group of destination links. To do this we use the conception of of the logic level. (http://wiki.oscada.org/HomePageEn/Doc/DAQ?v=2f4)

In accordance with the list item 2, the links provide transparent conversion of connection types and do not require special configuration here.

To satisfy the opportunities for access to archives, in accordance with the list item 3, links make check of the type of the attribute, and in the case of connection to the "Address", the address of linkage is put into the value.

In terms of the VCA, the dynamic links and configuration of the dynamics are the one process, to describe a configuration of which the tab "Processing" of the widgets is provided. The tab contains a table of configuration of the properties of the attributes of the widget and the text of calculation procedure of the widget.

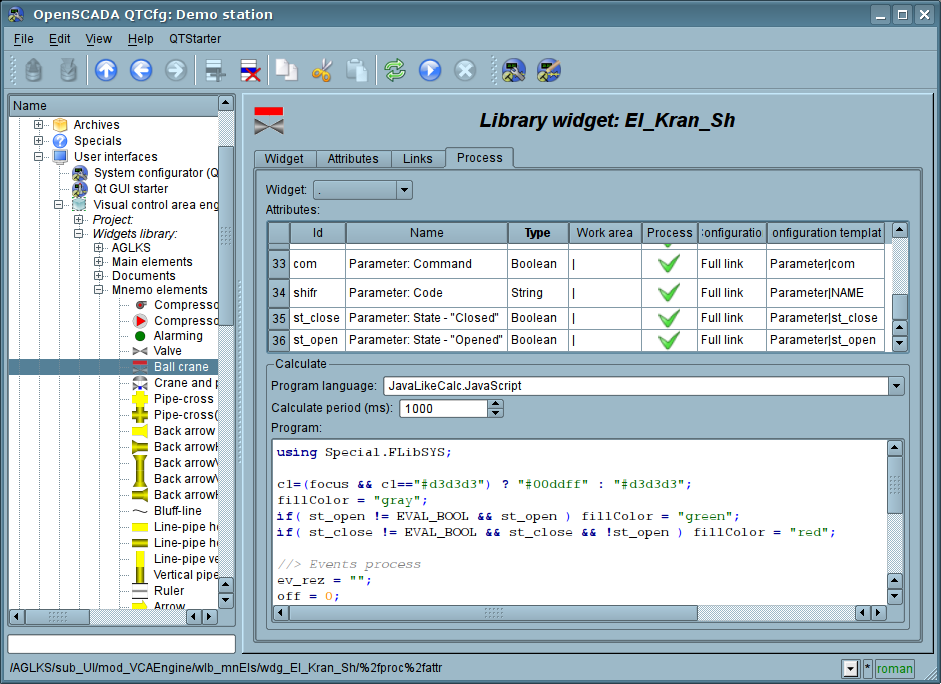
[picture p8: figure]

Figure. The tab "Processing" of the configuration page of the widget.

In addition to configuration fields of the attributes the column "Processing" in the table provides, for selective using of the attributes of the widgets in the computational procedure of the widget, and the columns "Configuration", "Configuration template", to describe the configuration of links.

The column "Configuration" allows you to specify the linkage type for the attribute of the widget:
Constant — in the tab of widget links the field for indication of a constant appears, for example of the special color or header for the template frames.
Input link — linkage with the dynamics for a read-only.
Output link — linkage with the dynamics just for a writing.
Full link — complete linkage with dynamic (read/write).
From style — take the value from the project's style.

The column "Configuration template" makes it possible to describe the groups of dynamic attributes. For example, it may be different types of parameters of subsystem "DAQ" and other widgets of the interface. Furthermore, in the case of correct formation of this field, the mechanism of automatically assign of the attributes with the only indication of the parameter of subsystem "DAQ" or the widget is working, which simplifies and accelerates the configuration process. The value of this column has the following format:
For constant: direct the attribute value.
For link: "{parameter}|{identifier}", where:
parameter — the group of the attribute;
identifier — identifier of the attribute; same the value is compared with the attributes of the DAQ parameters with automatic linkage, after the group link indication.
For style: identifier-name of the style field.

Installation of the links may be of several types, which are determined by the prefix:
val: — Direct download of the value through the links mechanism. For example, link: "val:100" loads in the attribute of the widget the value of the
100. It is often used in the case of absence of end point of the link, in order to direct value indicating.
prm: — Link to the attribute of the parameter or the parameter, in general, for a group of attributes, of subsystem "Data acquisition". For example, the link "prm:/LogicLev/experiment/Pi/var" implements the access of the attribute of the widget to the attribute of the parameter of subsystem "Data acquisition". Sign "(+)" at the end of the address indicate about successful linking and presence of the target. For object's type attributes allowed hierarchical access to the object concrete property by set the path through symbol '#', for example: "prm:/LogicLev/experiment/Pi/var#pr1/pr2".
wdg: — Link to an attribute of another widget or the widget, in general, for a group of attributes. For example, the link "wdg:/ses_AGLKS/pg_so/pg_1/pg_ggraph/pg_1/a_bordColor" performs the access of the attribute of one widget to the attribute of another one. Supported absolute and relative link's path. Start point of absolute point is root object of module "VCAEngine", then the first item of absolute address is a session or a project identifier. On session side first item is passed then set into a project links there work. For relative links by start point used a widget with the link set. The item ".." of parent node is a special item of the relative links.
arh: — A special type of link is only available for a particular attribute such as "Address", which allows you to connect directly to the archive values ("arh:CPU_load"). It may be useful to specify the archive as a source of data for primitive "Diagram".

Processing of the links occurs at a frequency of calculating the widget in the following order:
receiving of the data from input links;
perform of calculating of the script;
transmission of the values by the output links.

In the Figure the tab of links with the group assignment of the attributes by the only specifying the parameter is presented, and in next Figure — with the individual appointment of the attributes.

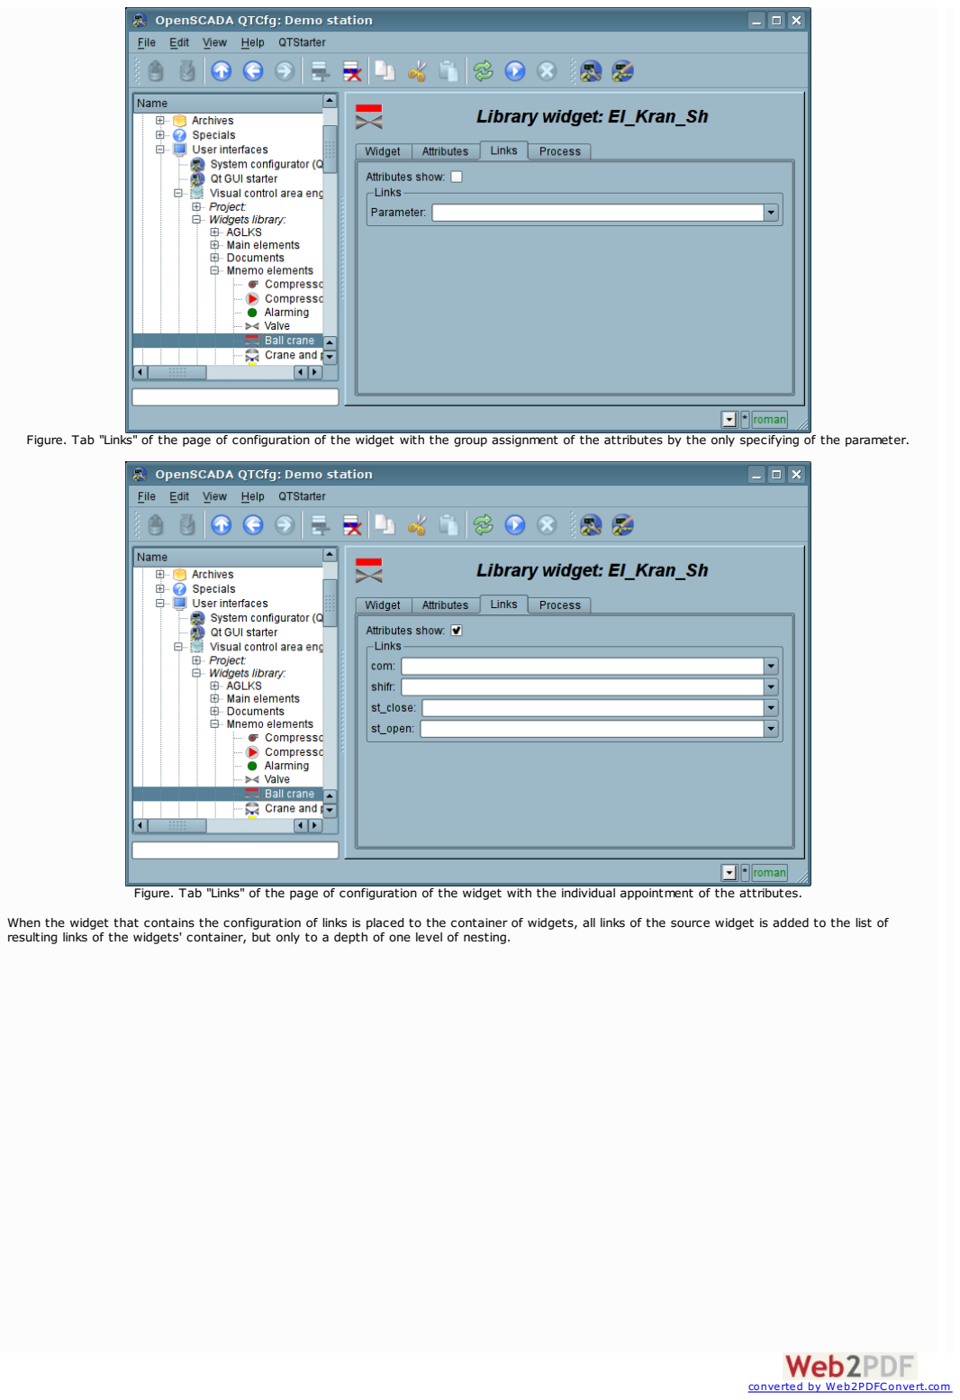
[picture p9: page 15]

Figure. Tab "Links" of the page of configuration of the widget with the group assignment of the attributes by the only specifying of the parameter.

Figure. Tab "Links" of the page of configuration of the widget with the individual appointment of the attributes.

When the widget that contains the configuration of links is placed to the container of widgets, all links of the source widget is added to the list of resulting links of the widgets' container, but only to a depth of one level of nesting.

Figure. Tab "Links" of the page of configuration of the container of widgets, including widgets with links.

The above shows that the links are set by the user in the configuration interface. However, for the possibility of creation of the frames for general use, with the function of providing detailed data of various sources of the same type, a dynamic linkage mechanism is necessary. Such mechanism is provided through a reserved key identifier "<page>" of the group of attributes of links in the frames of general purpose and dynamic linkage with the identifier "<page>" in the process of opening of the frame of general purpose by means of the signal from another widget.

Lets examine the example when we have the frame of general-purpose "Control panel of graph" and a lot of "Graphs" in different tabs. "Control panel of graph" has links with the templates:
tSek -> "<page>|tSek"
tSize -> "<page>|tSize"
trcPer -> "<page>|trcPer"
valArch -> "<page>|valArch"

At the same time, each widget "Graph" has the attributes tSek, tSize, trcPer and valArch. In the case of a calling of the opening signal of "Control panel of graph" from any widget "Graph" it is happening the linkage of the attributes of the "Control panel of graph" in accordance with the attribute specified in the template with the attribute of the widget "Graph". As a result, all changes in the "Control panel of graph" will be displayed on the graph by means of the link.

In the case of presence of external links to the parameters of subsystem "Data acquisition" in the widget "Graph", the links of "Control panel of graph" will be set on an external source. In addition, if in the "Control panel of graph" will be declared the links to the missing attributes directly in the widget "Graph", it will be made the search for the availability of such attributes from the external source, the first to which the link is directed, performing, thus, the addition of missing links.

To visualize this mechanism the table is cited.

Table. The mechanism of the dynamic linkage.
Attributes of the "Control panel of graph" (the template of dynamic linkage) | "Graph" attributes | Attributes of an external "Parameter" | The resulting link or an value of the linking attribute
tSek (<page>|tSek) | tSek | - | "Graph".tSek
tSize (<page>|tSize) | tSize | - | "Graph".tSize
trcPer (<page>|trcPer) | trcPer | - | "Graph".trcPer
valArch (<page>|valArch) | valArch | - | "Graph".valArch
var (<page>|var) | var | var | "Parameter".var
ed (<page>|ed) | - | ed | "Parameter".ed
max (<page>|max) | - | - | EVAL
min (<page>|min) | - | - | EVAL

/Home Page En / Doc / VC Aconcept / part 4 / part 10 (http://wiki.oscada.org/HomePageEn/Doc/VCAconcept/part4/part10?v=541) :: (edit) (http://wiki.oscada.org/HomePageEn/Doc/VCAconcept/part4/part10/edit)

## 3.9. The primitives of the widget

/Home Page En / Doc / VC Aconcept / part 4 / part 12 (http://wiki.oscada.org/HomePageEn/Doc/VCAconcept/part4/part12?v=syo) :: (edit) (http://wiki.oscada.org/HomePageEn/Doc/VCAconcept/part4/part12/edit)
Any newly created widget is based on one of several primitives (end element of the visualization) by installing of the kinship as directly to the primitive, as well as through the several intermediate user widgets. Each of the primitives contains a mechanism (logic) of the data model. A copy of the widget keeps the values of the properties of configuration of the the primitive specially for itself.

The tasks of the visualization interface includes support and work with the data model of the primitives of widgets. Primitives of the widget must be carefully developed and unitized in order to cover as many opportunities in the as possible to a smaller number of weakly connected with each other by their purpose primitives.

Table. The library of the primitives of widgets (basic elements of visualization)

Id | Name | Function
ElFigure | Elementary graphic figures | Primitive is the basis for drawing basic graphic shapes with their possible combinations in a single object. The support of the following basic figures is provided: Line. Arc. Bézier curve. Fill of the enclosed space. For all the figures contained in the widget it is set the common properties of thickness, color, etc., but this does not exclude the possibility of indicating the above attributes for each figure separately.
FormEl | Elements of the form | Includes support for standard form components: Line edit. Text edit. Check box. Button. Combo box. List. Tree. Table. Slider. Scroll bar.
Text | Text | Text element (labels). Characterized by the type of font, color, orientation and alignment.
Media | Media | Element of visualization of raster and vector images of various formats, playback of animated images, audio segments and video fragments.
Diagram | Diagram | Element of the diagram with the support of the visualization of the flow of several trends, the spectrum, XY diagrams of real-time data, ... .
Protocol | Protocol | Element of the protocol, visualizer of the system messages, with support for multiple operating modes.
Document | Document | The element of generating the reports, journals and other documentation on the basis of available in the system data.
Box | Container | Contains the mechanism for other widgets placement-including with the purpose of creation of new, more complex, widgets and pages of end visualization.
Function, in plane | Function of API of the object model of OpenSCADA | Not visual, on the side of execution, widget which allows to include a computing function of the object model of OpenSCADA in the VCA.

Table. The common set of properties/attributes in the widget
Id | Name | Number | Value
id | Id | - | Id of the element. The attribute is read-only, designed to provide information on the ID of the element.
path | Path | - | The path to the widget. The attribute is read-only and designed to provide full information about the location of the element.
parent | Parent | - | Path to the parent widget. The attribute is read-only and designed to provide information about the location of ancestor which the widget is inherited from.
owner | Owner | - | The widget owner and group in form "{owner}:{group}", by default the "root:UI".
perm | Permission | - | Permission to the widget in form "{user}{group}{other}" plus inheritance flag, includes the inheritance owner and it's permissions from upper widget. Where "user", "group" and "other" is: "__" — no any access; "R_" — read-only; "RW" — read and write. By default the 01000(inheritance).
root | Root | 1 | Id of the widget-primitive (basic element) which underlies the image of visualization of the widget.
name | Name | - | Name of the element. Modifiable the element name.
dscr | Description | - | Description of the element. Text field, serves for attachment to the widget of the brief description.
en | Enabled | 5 | The state of the element — "Enabled". Disabled element is not shown in the execution mode.
active | Active | 6 | The state of the element — "Active". Active element may receive focus in the execution mode, and thus receive keyboard and other events with their subsequent processing.
geomX | Geometry:x | 7 | Geometry, coordinate 'x' of the element position.
geomY | Geometry:y | 8 | Geometry, coordinate 'y' of the element position.
geomW | Geometry:width | 9 | Geometry, the width of the element.
geomH | Geometry:height | 10 | Geometry, the height of the element.
geomXsc | Geometry:x scale | 13 | The horizontally scale of the element.
geomYsc | Geometry:y scale | 14 | The vertical scale of the element.
geomZ | Geometry:z | 11 | Geometry, coordinate 'z' (level) of element on the page. It also defines order to transfer the focus through active elements.
geomMargin | Geometry:margin | 12 | Geometry, the margins of the element.
tipTool | Tip:tool | 15 | The text of a brief help or tip on this element. Usually is realized as a tool tip, while keeping your mouse cursor over the element.
tipStatus | Tip:status | 16 | Text information on the status of the element or the guide to action over the element. Usually is implemented in the form of a message in the status bar while keeping your mouse cursor over the element. * Modification from session of the attribute of the root page will record the message in the status bar of the visualization window session.
contextMenu | Context menu | 17 | Context menu in form strings list: "{ItName}:{Signal}". Where:

"ItName" — the item name;
"Signal" — the signal name, for it forming as "usr_{Signal}".
evProc | Events process | - | Attribute for storing of the script of the processing of event of direct control of user interface. Script is the list of commands to the visualization interface generated at the event receipt (attribute event). Direct events processing for pages manipulation in form: "{event}:{evSrc}:{com}:{prm}". Where: "event" — the waiting event; "evSrc" — the event source; "com" — the command of a session (open, next, prev); "prm" — the command parameter, where used: pg_so — direct name of the desired page with the prefix; 1 — name of a new page in a general way, without a prefix; * — the page is taken from the name of a previous page; $ — points the place of the opened page relative. Examples: ws_BtPress:/prev:prev:/pg_so/*/*/$ ws_BtPress:/next:next:/pg_so/*/*/$ ws_BtPress:/go_mn:open:/pg_so/*/mn/* ws_BtPress:/go_graph:open:/pg_so/*/ggraph

Additional attributes for items placed into the project in the role of a page.

pgOpen | Page:open state | - | Sign "The page is open". * Modification from session provides an immediate opening/closing the page.
pgNoOpenProc | Page:process no opened | - Sign "Execute the page, even if it is closed".
pgOpenSrc | Page:open source | 3 | Full address of the page which has opened this one. * Write/clear address of the widget — (opening initiator) performs an immediate opening/closing page. In the case of write the address and on certain conditions carried the dynamic linking of the current widget to the initiator.
pgGrp | Page:group | 4 | The group of the page.

Additional attributes of the execution mode — by the session.

event | Event | - | Special attributes for the collection of events of the widget in the list, which is divided by the new line. Access to the attribute is protected by the resource allocation in order to avoid loss of the events. The attribute is always available in the script of widget.
load | Load | -1 | The virtual command of the group data download.
focus | Focus | -2 | The special attribute of the indicating the fact of receiving the focus by an active widget. Attribute of the widget and of the the embedded widgets is available in the script of widget.
perm | Permission | -3 | The virtual attribute of the rights verification of active user on the viewing and control over the widget.

* — The special function of the widget attribute which running in a session of the project at any user's modification.

The visualization engine provides visualizer specific attributes activation. The process of activation does at a session of the project opening and minds for the project: creation of the specific attribute with pointed properties, at case it lack, and activation for modification tracing by the visualization engine, like to the attributes of forming primitive's shapes. For the specific attributes list of the visualizer you can see to proper documentation of the visualizer.

## Elementary graphic figures (ElFigure)

Primitive is the basis for drawing basic graphic shapes with their possible combinations in a single object. Taking into account the wide range of various shapes, which must be maintained by the primitive, and at the same time the primitive must be simple enough for using and, if possible, for implementation, it was decided to limit the list of the basic figures used for the construction of the resulting graphics to these figures: line, arc, Bézier curve and fill of the enclosed spaces. Based at these basic figures, it is possible to construct derived figures by combining the basic. In the context of the primitive, there is possibility to set the transparency of the color in the range [0...255], where '0' — complete transparency.

Table. A list of additional properties/attributes of the primitive "ElFigure"
Id | Name | Number | Value
lineWdth | Line:width | 20 | Line width.
lineClr | Line:color | 21 | Color name form "{color}[-{alpha}]", where: "color" — standard color name or digital view of three hexadecimal digit's number form "#RRGGBB"; "alpha" — alpha channel level [0...255], where 0 — complete transparent. Examples: "red" — solid red color; "#FF0000" — solid red color by digital code; "red-127" — half transparent red color.
lineStyle | Line:style | 22 | Line style (solid, dashed, dotted).
bordWdth | Border:width | 23 | Line border width. The zero width indicates the lack of border.
bordClr | Border:color | 24 | Border color (detailed in attribute 21).
fillColor | Fill:color | 25 | Fill color (detailed in attribute 21).
fillImg | Fill:image | 26 | Image name in form "[{src}:]{name}", where: "src" — the image source: file — direct from local file by the path; res — from the DB mime resources table. "name" — the file path or the resource mime Id. Examples: "res:backLogo" — from the DB mime resources table for id "backLogo"; "backLogo" — like previous; "file:/var/tmp/backLogo.png" — from local file by the path "/var/tmp/backLogo.png".
orient | Orientation angle | 28 | The rotation angle of the content of widget.
elLst | Element's list | 27 | List of graphic primitives in the following format: Line. Record form in the list, for static and dynamic parameters (may mix): "line:({x}|{y}):({x}|{y})[:{width}[:{color}[:{bord_w}[:{bord_clr}[:{line_stl}]]]]]" (http://www.web2pdfconvert.com?ref=PDF) "line:{p1}:{p2}[:w{n}[:c{n}[:w{n}[:c{n}[:s{n}]]]]]"

Arc. Record form in the list, for static and dynamic parameters (may mix): "arc:({x}|{y}):({x}|{y}):({x}|{y}):({x}|{y}):({x}|{y})[:{width}[:{color}[:{bord_w}[: {bord_clr}[:{line_stl}]]]]]" "arc:{p1}:{p2}:{p3}:{p4}:{p5}[:w{n}[:c{n}[:w{n}[:c{n}[:s{n}]]]]]"

p1, p2 — starting and ending points of an elliptic arc, respectively; p3 — the center of the arc;
p4 — first radius;
p5 — second radius.
Bézier curve. Record form in the list, for static and dynamic parameters (may mix): "bezier:({x}|{y}):({x}|{y}):({x}|{y}):({x}|{y})[:{width}[:{color}[:{bord_w}[:{bord_clr} [:{line_stl}]]]]]"
"bezier:{p1}:{p2}:{p3}:{p4}[:w{n}[:c{n}[:w{n}[:c{n}[:s{n}]]]]]"
Fill. Record form in the list:
"fill:({x}|{y}):({x}|{y}):...:({x}|{y})[:{fill_clr}[:{fill_img}]]" "fill:{p1}:{p2}:...:{pN}[:c{n}[:i{n}]]" Where:

x, y — direct point (x,y), coordinate in float point pixels;
p1 ... pN — dynamic point 1...N;
width, bord_w — direct line and border width in float point pixels;
w{n} — dynamic width 'n';
color, bord_clr, fill_clr — direct line, border and fill color name or 32bit code with alpha: {name}[-{AAA}], #RRGGBB-AAA;
c{n} — dynamic color 'n';
line_stl — direct line style: 0-Solid, 1-Dashed, 2-Dotted;
s{n} — dynamic style 'n';
fill_img — direct fill image in form "[{src}%3A]{name}", where: "src" — image source:
file — direct from local file by the path; res — from the DB mime resources table. "name" — the file path or the resource mime Id. i{n} — dynamic fill image 'n'.
For example:
line:(50|25):(90.5|25):2:yellow:3:green:2 arc:(25|50):(25|50):1:4:(25|50)::#000000-0 fill:(25|50):(25|50):c2:i2 fill:(50|25):(90.5|25):(90|50):(50|50):#d3d3d3:h_31

The attributes for each point from the list of graphic figures elLst

p{n}x | Point {n}:x | 30+n*6 | Coordinates 'x' of the point n.
p{n}y | Point {n}:y | 30+n*6+1 | Coordinates 'y' of the point n.
w{n} | Width {n} | 30+n*6+2 | Width n.
с{n} | Color {n} | 30+n*6+3 | Color n (detailed in attribute 21).
i{n} | Image {n} | 30+n*6+4 | Image n (detailed in attribute 26).
s{n} | Style {n} | 30+n*6+5 | Style n.

## Element of the form(FormEl)

Primitive is intended to provide the standard form elements to the user. The general list of attributes depends on the type of element.

Table. A set of additional properties/attributes of the primitive "FormEl"
Id | Name | Number | Value
elType | Element's type | 20 | Type of the element: "Line edit", "Text edit", "Check box", "Button", "Combo box", "List", "Tree", "Table", "Slider", "Scroll bar". On its value it depends a list of additional attributes.

Line edit:

value | Value | 21 | The contents of the line.
view | View | 22 | Type of the editing line: "Text", "Combobox", "Integer", "Real", "Time", "Date", "Date and Time".
cfg | Configuration | 23 | Configuration of the line. The format of the value of the field for different types of lines: Text — the formated input configuration with parameters: A — ASCII alphabetic character required. A-Z, a-z. a — ASCII alphabetic character permitted but not required. N — ASCII alphanumeric character required. A-Z, a-z, 0-9. n — ASCII alphanumeric character permitted but not required. X — Any character required. x — Any character permitted but not required. 9 — ASCII digit required. 0-9. 0 — ASCII digit permitted but not required. D — ASCII digit required. 1-9. d — ASCII digit permitted but not required (1-9). # — ASCII digit or plus/minus sign permitted but not required.
| | | H — Hexadecimal character required. A-F, a-f, 0-9. h — Hexadecimal character permitted but not required. B — Binary character required. 0-1. b — Binary character permitted but not required.

> — All following alphabetic characters are uppercased. < — All following alphabetic characters are lowercased.

! — Switch off case conversion.
\\ — Use to escape the special characters listed above to use them as separators. Combobox — list of values the editable combobox by lines.
Integer — integer value configuration in form: "{Min}:{Max}:{ChangeStep}:{Prefix}:{Suffix}". Real — real value configuration in form: "{Min}:{Max}:{ChangeStep}:{Prefix}:{Suffix}: {SignsAfterDot}".
Time, Date, Date and time — to form the date following the template with parameters:
d — number of the day (1-31);
dd — number of the day (01-31);
ddd — acronym of the day ("Mon" ... "Sun");
dddd — the full name of the day ("Monday" ... "Sunday"); M — number of the month (1-12);
MM — number of the month (01-12);
MMM — acronym of the month ("Jan" ... "Dec");
MMMM — the full name of the month ("January" ... "December"); yy — last two digits of the year;
yyyy — full year;
h — hour (0-23);
hh — hour (00-23); m — minutes (0-59); mm — minutes (00-59);

s — seconds (0-59);
ss — seconds (00-59);
AP,ap — to display AM/PM or am/pm.
confirm | Confirm | 24 | Enable the confirm mode.
font | Font | 25 | Font name form "{family} {size} {bold} {italic} {underline} {strike}", where: "family" — font family, for spaces use symbol '_', like: "Arial", "Courier", "Times_New_Roman"; "size" — font size in pixels; "bold" — font bold (0 or 1); "italic" — font italic (0 or 1); "underline" — font underlined (0 or 1); "strike" — font struck (0 or 1). Examples: "Arial 10 1 0 0 0" — Arial font size 10 pixels and bold.

Text edit:

value | Value | 21 | The contents of the editor.
wordWrap | Word wrap | 22 | Automatic division of text by the words.
confirm | Confirm | 24 | Enable confirm mode.
font | Font | 25 | Font name form "{family} {size} {bold} {italic} {underline} {strike}" (details above).

Check box:

name | Name | 26 | Name/label of the checkbox.
value | Value | 21 | Value of the checkbox.
font | Font | 25 | Font name form "{family} {size} {bold} {italic} {underline} {strike}" (details above).

Button:

name | Name | 26 | Name, the inscription on the button. Allowed symbols '\n' for multiple line names.
value | Value | 21 | The value, different for modes: "Standard" — repeating parameters of events on holding "{delay}-{interval}", time in milliseconds; "Checkable" — toggle value; "Menu" — addresses of menu elements list like "/grp1/grp2/item1"; "Load" — description line "{FilesTemplate}|{Header}|{FileByDefault}" and loaded file content. Files template like "Images (*.png *.xpm *.jpg);;CSV-file (*.csv)". "Save" — description line "{FilesTemplate}|{Header}|{FileByDefault}" and saved file content. Files template like before.
img | Image | 22 | The image on the button. Image name in form "[{src}:]{name}", where: "src" — the image source: file — direct from local file by the path; res — from the DB mime resources table. "name" — the file path or the resource mime Id. Examples: "res:backLogo" — from the DB mime resources table for Id "backLogo"; "backLogo" — like previous; "file:/var/tmp/backLogo.png" — from local file by the path "/var/tmp/backLogo.png".
color | Color | 23 | Color of the button. Color name form "{color}[-{alpha}]", where: "color" — the standard color name or digital view of three hexadecimal digit's number form "#RRGGBB"; "alpha" — the alpha channel level [0...255]. Examples: "red" — solid red color; "#FF0000" — solid red color by the digital code; "red-127" — half transparent red color.
colorText | Color:text | 27 | The color of the text. (details above)
mode | Mode | 24 | The button operation mode: "Standard" — normal button which allow events repeat on it hold (the parameters into "value"); "Checkable" — fixed button (values into "value"); "Menu" — open menu on press (items list into "value"); "Load" — provides user-space small files loading through the visual interface; on the mode the button press will open selection file dialog for loading and the file content next saving to the attribute "value"; "Save" — provides user-space small files saving through the visual interface; on the file content writing to "value" attribute for user will open selection/set file dialog and next saving the attribute "value" content to the file and next the attribute "value" will set clean.

font | Font | 25 | Font name form "{family} {size} {bold} {italic} {underline} {strike}" (details above). Combo box, List, Tree:
value | Value | 21 | Current value of the list.
items | Items | 22 | The entries of the list or hierarchical items list of tree in path "/{DIR}/{DIR}/{ITEM}".
font | Font | 25 | Font name form "{family} {size} {bold} {italic} {underline} {strike}" (details above).

Table:

set | Setting value | 23 | The value of edition of a cell of the table which address into the event "ws_TableEdit_{colN}_{rowN}".
value | Value | 21 | Address of the selected item. It changing follows by the signal "ws_TableChangeSel". The address format depends from the table's selection mode: "Cell" — the cell address in format "{row}:{col}". "Row", "Column" — the row-column number or the row-column key's cell content, which sets by the attribute "keyID".
items | Elements | 22 | The table structure and content in XML view: <tbl> <h><s>{Header1}</s><s>{Header2}</s></h> <r><s>{Row1Column1String}</s><i>{Row1Column1Integer}</i></r> <r><b>{Row2Column1Logical}</b><r>{Row2Column2Real}</r></r> </tbl>
| | | The tags: "tbl" — Table, the properties at all: "sel" — the selection mode of the table items: "row" — by rows, "col" — by columns, "cell" — by cells (by default); "keyID" — the key's row-column number, for the selection value get; "colsWdthFit" — fit the columns (which size unfixed) size to fill for full the table width; "hHdrVis", "vHdrVis" — horizontal, vertical header visibility set; "sortEn" — direct sorting by columns enable. "h" — The headers size, allowed attributes about cell-tag of the header, for the column as a whole: "width" — the column width, in pixels or percents (10%); "edit" — allowing to the cells of the row edition (0 or 1), by default — no (0); "color" — the column color as a whole into the color name or code; "colorText" — the column's text color as a whole into the color name or code; "font" — the column's text font in typical OpenSCADA's string; "sort" — sorting by the column [0 - Descending; 1 - Ascending]. "r" — the row of values, allowed attributes: "color" — the row color as a whole into the color name or code; "colorText" — the row's text color as a whole into the color name or code; "font" — the row's text font in typical OpenSCADA's string. "s", "i", "r", "b" — the data type's cells "String", "Integer", "Real" and "Logical". Allowed attributes: "color" — the cell's background color; "colorText" — the cell's text color into the color name or code; "font" — the cell's text font in typical OpenSCADA's string; "img" — the cell's image into form "[{src}:]{name}", the details above; "edit" — allowing to the cell of the row edition (0 or 1), by default — no (0).
font | Font | 25 | Font name form "{family} {size} {bold} {italic} {underline} {strike}" (the details above).

Slider and Scroll Bar:

value | Value | 21 | The slider position.
cfg | Configuration | 22 | Configuration of the slider in the format: "{VertOrient}:{Min}:{Max}:{SinglStep}:{PageStep}". Where: "VertOrient" — sign (0 or 1) of a vertical orientation, the default is the horizontal orientation; "Min" — minimum value; "Max" — maximum value; "SinglStep" — the size of a single step; "PageStep" — the size of a page step.

## Text element (Text)

This primitive is designed to display the plain text used as labels, and different signatures. With the reason of creating a simple frequent decorations the primitive must support the surrounding of the text by frame.

Table. The list of additional properties/attributes of the primitive "Text"
Id | Name | Number | Value
backColor | Background:color | 20 | Background color. Color name in form "{color}[-{alpha}]", where: "color" — standard color name or digital view of three hexadecimal digit's number form "#RRGGBB"; "alpha" — alpha channel level [0...255], where 0 - is full transparent. Examples: "red" — solid red color; "#FF0000" — solid red color by the digital code; "red-127" — half transparent red color.
backImg | Background:image | 21 | Background image. The image name in form "[{src}:]{name}", where: "src" — the image source: file — direct from local file by the path; res — from the DB mime resources table. "name" — the file path or the resource mime Id. Examples: "res:backLogo" — from DB mime resources table for Id "backLogo"; "backLogo" — like previous; "file:/var/tmp/backLogo.png" — from local file by the path "/var/tmp/backLogo.png".
bordWidth | Border:width | 22 | Border width.
bordColor | Border:color | 23 | Border color (detailed in attribute 20).

bordStyle font | Border:style Font | 24 25 | Border style: "None", "Dotted", "Dashed", "Solid", "Double", "Groove", "Ridge", "Inset", "Outset". Font name form "{family} {size} {bold} {italic} {underline} {strike}", where: "family" — font family, for spaces use symbol '_', like: "Arial", "Courier", "Times_New_Roman"; "size" — font size in pixels; "bold" — font bold (0 or 1); "italic" — font italic (0 or 1); "underline" — font underlined (0 or 1); "strike" — font struck (0 or 1). Examples: "Arial 10 1 0 0 0" — Arial font size 10 pixels and bold.
color | Color | 26 | Text color (detailed in attribute 20).
orient | Orientation angle | 27 | Orientation of text, rotation on angle.
wordWrap | Word wrap | 28 | Automatic division of text by words.
alignment | Alignment | 29 | Alignment of the text: "Top left", "Top right", "Top center", "Top justify", "Bottom left", "Bottom right", "Bottom justify", "V center left", "V center right", "Center", "V center justify".
text | Text | 30 | Text value. Use "%{x}" for argument "x" (from 1) value insert to.
numbArg | Arguments number | 40 | Arguments number.

Attributes of the arguments

arg{x}val | Argument {x}:value | 50+10*x | Argument x value.
arg{x}tp | Argument {x}:type | 50+10*x+1 | Argument x type: "Integer", "Real", "String".
arg{x}cfg | Argument {x}:config | 50+10*x+2 | Argument x configuration: "String": {len} — string length; "Real": {wdth};{form};{prec} — value width, the form of ('g', 'e', 'f') and the precision; "Integer": {len} — value length.

## Element of visualization of media materials (Media)

This primitive is designed to play different media materials, ranging from simple images to the full audio and video streams.

Table. A set of additional properties/attributes of primitive "Media"
Id | Name | Number | Value
backColor | Background:color | 20 | Background color. Color name in form "{color}[-{alpha}]", where: "color" — standard color name or digital view of three hexadecimal digit's number form "#RRGGBB"; "alpha" — alpha channel level [0...255], where 0 - is full transparent. Examples: "red" — solid red color; "#FF0000" — solid red color by the digital code; "red-127" — half transparent red color.
backImg | Background:image | 21 | Background image. The image name in form "[{src}:]{name}", where: "src" — the image source: file — direct from local file by the path; res — from the DB mime resources table. "name" — the file path or the resource mime Id. Examples: "res:backLogo" — from DB mime resources table for Id "backLogo"; "backLogo" — like previous; "file:/var/tmp/backLogo.png" — from local file by the path "/var/tmp/backLogo.png".
bordWidth | Border:width | 22 | Border width.
bordColor | Border:color | 23 | Border color (detailed in attribute 20).
bordStyle | Border:style | 24 | Border style: "None", "Dotted", "Dashed", "Solid", "Double", "Groove", "Ridge", "Inset", "Outset".
src | Source | 25 | Media source name in form "[{src}:]{name}", where: "src" — source: file — direct from local (visualizer or engine) file by the path; res — from the DB mime resources table; stream — Stream URL for the video and the audio play. "name" — the file path or the resource mime Id. Examples: "res:workMedia" — from DB mime resources table for Id "workMedia"; "workMedia" — like previous; "file:/var/tmp/workMedia.mng" — from local file by path "/var/tmp/workMedia.mng"; "stream:http://localhost.localhost:5050" — video and audio stream play from URL.
type | Type | 27 | Media type variant: "Image" — raster or vector(can not support) image, like: PNG, JPEG, GIF, SVG; "Animation" — simple animation image, like: GIF, MNG; "Full video" — full video, audio or stream, like: OGG, OGM, AVI, MKV, MPG, MP3, MP4.
areas | Map areas | 28 | Number of active areas.

The attributes of the image (Image)

fit | Fit to the widget
size
26 | Sign "Coordinate the contents with the size of the widget".

The attributes of the video (Movie)

fit | Fit to the widget size | 26 | Sign "Coordinate the contents with the size of the widget".
speed | Play speed | 29 | The speed of playback, as a percentage from the original speed. If the value is less than 1%, the playback stops.

The attributes of the full video (Full video)

play | Play | 29 | Video/audio - "Play".
roll | Roll play | 30 | Roll play on the finish.
pause | Pause | 31 | Playing pause.
size | Size | 32 | Total video size (in milliseconds).
seek | Seek | 33 | Seek video playing (in milliseconds).
volume | Volume | 34 | Sound volume [0...100].

Active areas

area{x}shp | Area {x}:shape | 40+3*x | Type of the area x: "Rect", "Poly", "Circle".
area{x}coord | Area {x}:coordinates | 40+3*x+1 | The coordinates of area x, are separated by commas: "x1,y1,x2,y2,xN,yN"
area{x}title | Area {x}:title | 40+3*x+2 | Title of the area x.

## Element of constructing diagrams/trends (Diagram)

This primitive targeted to construct various diagrams, including graphs/trends showing ongoing process and the archive data. Following types of the diagrams are implemented:
"Graph" — builds a graph of the values of a parameter in time
"Spectrum" — builds the frequency spectrum of values of a parameter. Window of the data of frequency spectrum is formed on the basis of the size of the widget horizontally, in pixels, and the available data of the parameters imposed on the horizontal grid size. In this regard, the minimum frequency is determined by the value of the attribute "tSize" — "1/tSize", and maximum frequency of allocated frequencies is determined by half-width of the graph in pixels multiplied by the minimum frequency "width/(2*tSize)".
"XY" — builds the two-dimensional graph of values of a parameter, by pairs to one graphic, where paired by axis Y (0,2,4...) and unpaired by axis X (1,3,5...). Sets time of the data range uses for values of the parameter obtain by axis X and Y, with follow sorting by the axis X and the imaging.

For all the diagram types possible as the data source sets:
parameter of the subsystem "DAQ";
values archive;
direct data block from user.

Supported tracing of the current values and the values from the archive, and also the possibility of building the graphs of the parameters which have no archive of values, by the current values accumulation into the diagram buffer and only at the diagram active visibility moment.

The process of access to the archive data is optimized, by means of an intermediate buffer for the display, as well as the package of traffic data in the query, by way the data lead to quality enough for display.

Table. A list of additional properties/attributes of the primitive "Diagram"
Id | Name | Number | Value
backColor | Background:color | 20 | Background color. Color name in form "{color}[-{alpha}]", where: "color" — standard color name or digital view of three hexadecimal digit's number form "#RRGGBB"; "alpha" — alpha channel level [0...255], where 0 - is full transparent. Examples: "red" — solid red color; "#FF0000" — solid red color by the digital code; "red-127" — half transparent red color.
backImg | Background:image | 21 | Background image. The image name in form "[{src}:]{name}", where: "src" — the image source: file — direct from local file by the path; res — from the DB mime resources table. "name" — the file path or the resource mime Id. Examples: "res:backLogo" — from DB mime resources table for Id "backLogo"; "backLogo" — like previous; "file:/var/tmp/backLogo.png" — from local file by the path "/var/tmp/backLogo.png".
bordWidth | Border:width | 22 | Border width.
bordColor | Border:color | 23 | Border color (detailed in attribute 20).
bordStyle | Border:style | 24 | Border style: "None", "Dotted", "Dashed", "Solid", "Double", "Groove", "Ridge", "Inset", "Outset".
trcPer | Tracing period (s) | 25 | Mode and frequency of the tracing.
type | Type | 26 | Diagram type: "Trend", "Spectrum", "XY".

General attributes for all the types

tSek | Time:seconds | 27 | Current time, seconds.
tUSek | Time:microseconds | 28 | Current time, microseconds.
tSize | Size, seconds | 29 | Size of the trend, seconds.
curSek | Cursor:seconds | 30 | Cursor position, seconds.
curUSek | Cursor:usek | 31 | Cursor position, microseconds.
curColor | Cursor:color | 32 | Cursor color.
sclColor | Scale:color | 33 | Color of the scale/grid (detailed in attribute 20).
sclHor | Scale:horizontal | 34 | Horizontal mode of the scale/grid: "No draw", "Grid", "Markers", "Grid and markers", "Grid (log)", "Markers (log)", "Grid and markers (log)".
sclHorScl | Scale:horizontal scale (%) | 44 | Graphics's horizontal scale in percents, excluding for type "XY".
sclHorSclOff | Scale:horizontal scale offset (%) | 45 | Offset of graphics's horizontal scale in percents, excluding for type "XY".
sclVer | Scale:vertical | 35 | Vertical mode of the scale/grid: "No draw", "Grid", "Markers", "Grid and markers", "Grid (log)", "Markers (log)", "Grid and markers (log)".
sclVerScl | Scale:vertical scale | 40 | Graphics's vertical scale in percents.

| (%)
sclVerSclOff | Scale:vertical scale offset (%) | 41 | Offset of graphics's vertical scale in percents.
sclMarkColor | Scale:Markers:color | 36 | Color of the markers of the scale/grid (detailed in attribute 20).
sclMarkFont | Scale:Markers:font | 37 | Font of the markers of scale/grid. Font name form "{family} {size} {bold} {italic} {underline} {strike}", where: "family" — font family, for spaces use symbol '_', like: "Arial", "Courier", "Times_New_Roman"; "size" — font size in pixels; "bold" — font bold (0 or 1); "italic" — font italic (0 or 1); "underline" — font underlined (0 or 1); "strike" — font struck (0 or 1). Examples: "Arial 10 1 0 0 0" — Arial font size 10 pixels and bold.
valArch | Value archiver | 38 | Value archiver in form "{ArchMod}.{ArchivatorId}".
valsForPix | Values for pixel | 42 | The number of values per pixel. Increase to enhance the accuracy of export at large time intervals.
parNum | Parameters number | 39 | The number of parameters that can be displayed on the one trend.

Attributes for type: "Graph"

sclHorPer Scale:horizontal
grid size, seconds
43 | Fixed a grid period of horizontal scale, disable automatic calculation for the grid period. Activated if the
periods number into overall size more for two and one period size more for 15 pixels.

Individual attributes of the parameters of trend/graph/XY

prm{X}addr Parameter {X}
:address

50+10*
{X}

Full address to DAQ attribute of a parameter X or to an archive.
Also supported direct data set by the prefixes:
"data:{XMLNodeData}" — drawing from the direct set data;
"line:{value}" — drawing the horizontal line by the value, no sense have for type "XY". Example:
"/DAQ/System/AutoDA/MemInfo/use" — address to attribute "use" of parameter "MemInfo" of controller "AutoDA" of DAQ module "System";
"/Archive/va_CPULoad_load" — address to archive "CPULoad_load".
"data:<d s="1" aprox="1" tm="1369465209" tm_grnd="1369465200" per="1">
0 3.14
1 3.141
5 3.1415</d>" — data for 10 seconds and period 1 second from "25.05.2013 10:00:00"; at pass "tm" and "tm_grnd" it will sets values from the diagram range, and also by set attribute "s" it will allows the time set into seconds; "aprox" — approximate the throughout from one point to other instead the substitution previous value into all the periodical points (typically it is from packing); "line:3.14159265" — horizontal line into value "3.14159265".
prm{X}bordL | Parametr {X}:view border:lower | 50+10* {X}+1 | Lower limit of the parameter X.
prm{X}bordU | Parametr {X}:view border:upper | 50+10* {X}+2 | Upper limit of the parameter X.
prm{X}color | Parametr {X}:color | 50+10* {X}+3 | Color for display of the trend of the parameter X (detailed in attribute 20).
prm{X}width | Parametr {X}:width | 50+10* {X}+6 | Line width for display of the trend of the parameter X, in pixels.
prm{X}scl | Parametr {X}:scale | 50+10* {X}+5 | Separated vertical scale mode of the parameter X: "Global", "Markers", "Grid and markers", "Markers (log)", "Grid and markers (log)".
prm{X}val | Parametr {X}:value | 50+10* {X}+4 | Value of the parameter X under the cursor.
prm{X}prop | Parametr {X}:properties | 50+10* {X}+7 | Real archive properties in form "{BegArh}:{EndArh}:{DataPeriod}", where "BegArh", "EndArh", "DataPeriod" — begin, end and period of archive's data in seconds, real up to microseconds (1e-6).

## Element of building the protocols based on the archives of messages (Protocol)

This primitive is designed to visualize the data of the archive of messages through the formation of protocols with different ways of visualization, starting from a static scanning view and finishing with dynamic tracing of protocol of message.

Table. A list of additional properties/attributes of the primitive "Protocol"
Id | Name | Number | Value
backColor | Background:color | 20 | Background color. Color name in form "{color}[-{alpha}]", where: "color" — standard color name or digital view of three hexadecimal digit's number form "#RRGGBB"; "alpha" — alpha channel level [0...255], where 0 - is full transparent. Examples: "red" — solid red color; "#FF0000" — solid red color by the digital code; "red-127" — half transparent red color.
backImg | Background:image | 21 | Background image. The image name in form "[{src}:]{name}", where: "src" — the image source: file — direct from local file by the path; res — from the DB mime resources table. "name" — the file path or the resource mime Id. Examples: "res:backLogo" — from DB mime resources table for Id "backLogo"; "backLogo" — like previous; "file:/var/tmp/backLogo.png" — from local file by the path "/var/tmp/backLogo.png".
font | Font | 22 | Font of markers of scale/grid. Font name form "{family} {size} {bold} {italic} {underline} {strike}", where: "family" — font family, for spaces use symbol '_', like: "Arial", "Courier", "Times_New_Roman"; "size" — font size in pixels; "bold" — font bold (0 or 1); "italic" — font italic (0 or 1);

"underline" — font underlined (0 or 1);
"strike" — font struck (0 or 1).
Examples:
"Arial 10 1 0 0 0" — Arial font size 10 pixels and bold.
headVis | Header visible | 23 | Show header for table or not.
time | Time, seconds | 24 | Current time, seconds.
tSize | Size, seconds | 25 | Query size, seconds. Set value to '0' for get all alarms, for "lev" < 0.
trcPer | Tracing period (s) | 26 | Mode and frequency of tracing.
arch | Archivator | 27 | Messages archivator in form "{ArchMod}.{ArchivatorId}".
tmpl | Template | 28 | Category template or regular expression "/{re}/". For template reserved special symbols: '*' — any multiply symbols group; '?' — any one symbol; '\\' — use for shield special symbols.
lev | Level | 29 | The level of messages. Set value to < 0 for get the current alarms.
viewOrd | View order | 30 | View order: "By time", "By level", "By category", "By messages", "By time (reverse)", "By level (reverse)", "By category (reverse)", "By messages (reverse)".
col | View columns | 31 | Visible and order columns list separated by symbol ';'. Supported columns: "pos" — row number; "tm" — date and time of the message; "utm" — microseconds part of the time of the message; "lev" — level of the message; "cat" — category of the message; "mess" — the message text.
itProp | Item properties | 32 | Item's properties number.

Individual attributes of the item's properties

it{X}lev | Item {X}:level | 40+5* {X} | Criterion: element's level X, more or equal for pointed.
it{X}tmpl | Item {X}:template | 40+5* {X}+1 | Criterion: element's category template X (detailed in attribute 28).
it{X}fnt | Item {X}:font | 40+5* {X}+2 | Element X font (detailed in attribute 22).
it{X}сolor | Item {X}:color | 40+5* {X}+3 | Element X color (detailed in attribute 20).
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

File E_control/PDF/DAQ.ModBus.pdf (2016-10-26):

# The modules <ModBus> of subsystem “Data acquisition” and subsystem “Transport protocols”

Parameter | Module 1 | Module 2
ID: | ModBus
Name: | ModBus
Type: | DAQ | Protocol
Source: | daq_ModBus.so
Version: | 1.3.0 | 0.6.4
Author: | Roman Savochenko
Translated: | Maxim Lysenko
Description: | Provides implementation of client service of the protocol ModBus. Modbus/TCP, Modbus/RTU and Modbus/ASCII protocols are supported. | Provides implementation of protocols ModBus. Modbus/TCP, Modbus/RTU and Modbus/ASCII protocols are supported.
License: | GPL

## Contents table

The modules <ModBus> of subsystem “Data acquisition” and subsystem “Transport

## Introduction

ModBus — communication protocol based on the client-server architecture. It was developed by Modicon for using in the programmable logic controllers (PLC). It became the de facto standard in the industry and is widely used for the connection of industrial electronic equipment. Used to transfer data via serial line RS-485, RS-422, RS-232, and network TCP/IP. Currently supported non-profit organization ModBus-IDA.
There are three modes of the protocol: ModBus/RTU, ModBus/ASCII and ModBus/TCP. The first two use the serial communication lines (mostly RS-485, less RS-422/RS-232), the last uses TCP/IP network to transfer data.
Module of the data acquisition provides an opportunity to gather the information from various devices by means of the protocol ModBus in all modes. Also, the module implements the functions of the horizontal reservation, namely, working in conjunction with the remote station of the same level. At the same time, the module of the protocol allows you to create and issue data by means of the protocol ModBus in various modes, and through interfaces that are supported by modules of subsystem "Transports".

OpenSCADA - DAQ.ModBus, Protocol.ModBus 2
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

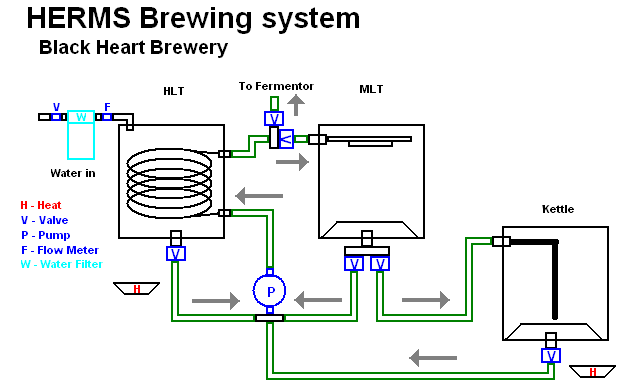
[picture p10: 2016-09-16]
Info/Frame/HERMSv2.png

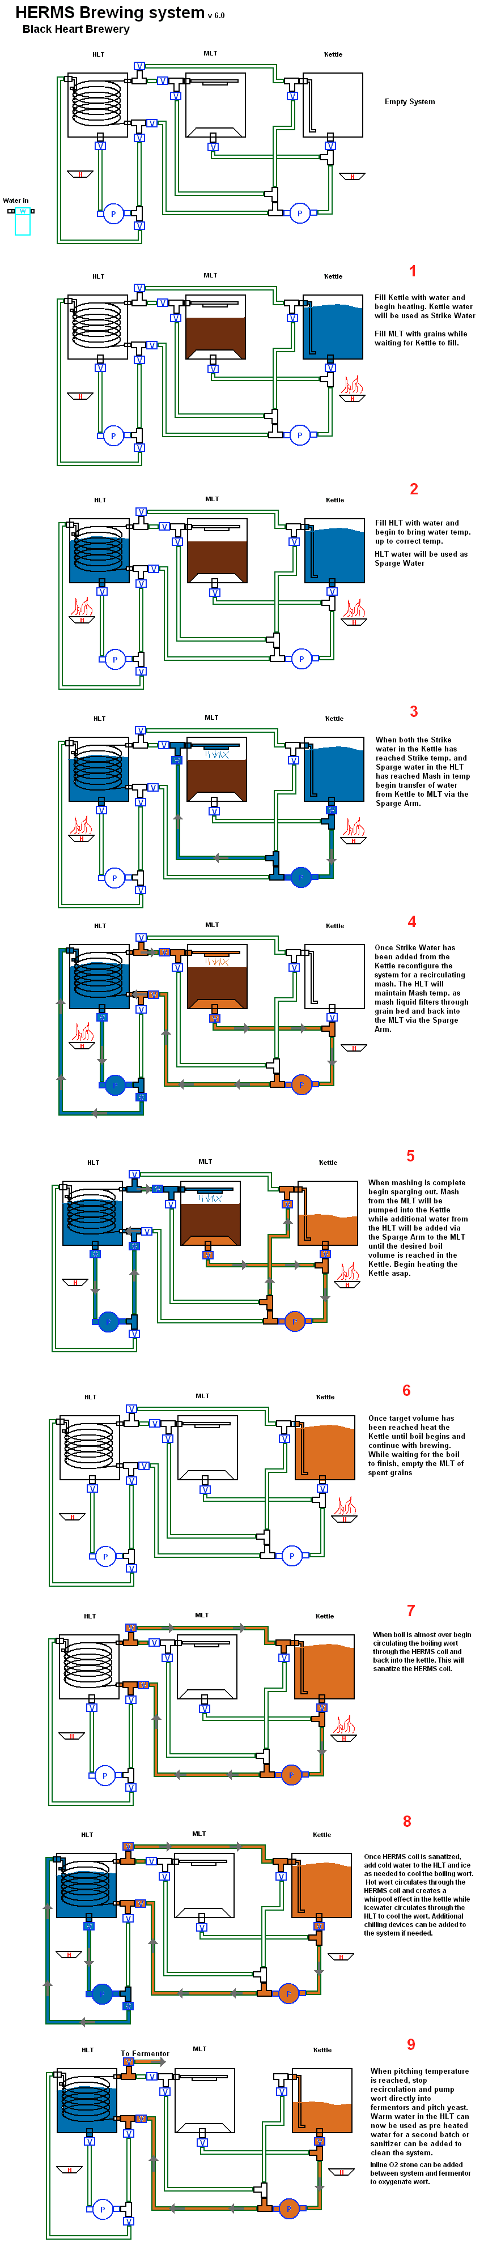
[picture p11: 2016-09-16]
Info/Frame/HERMSv6.png

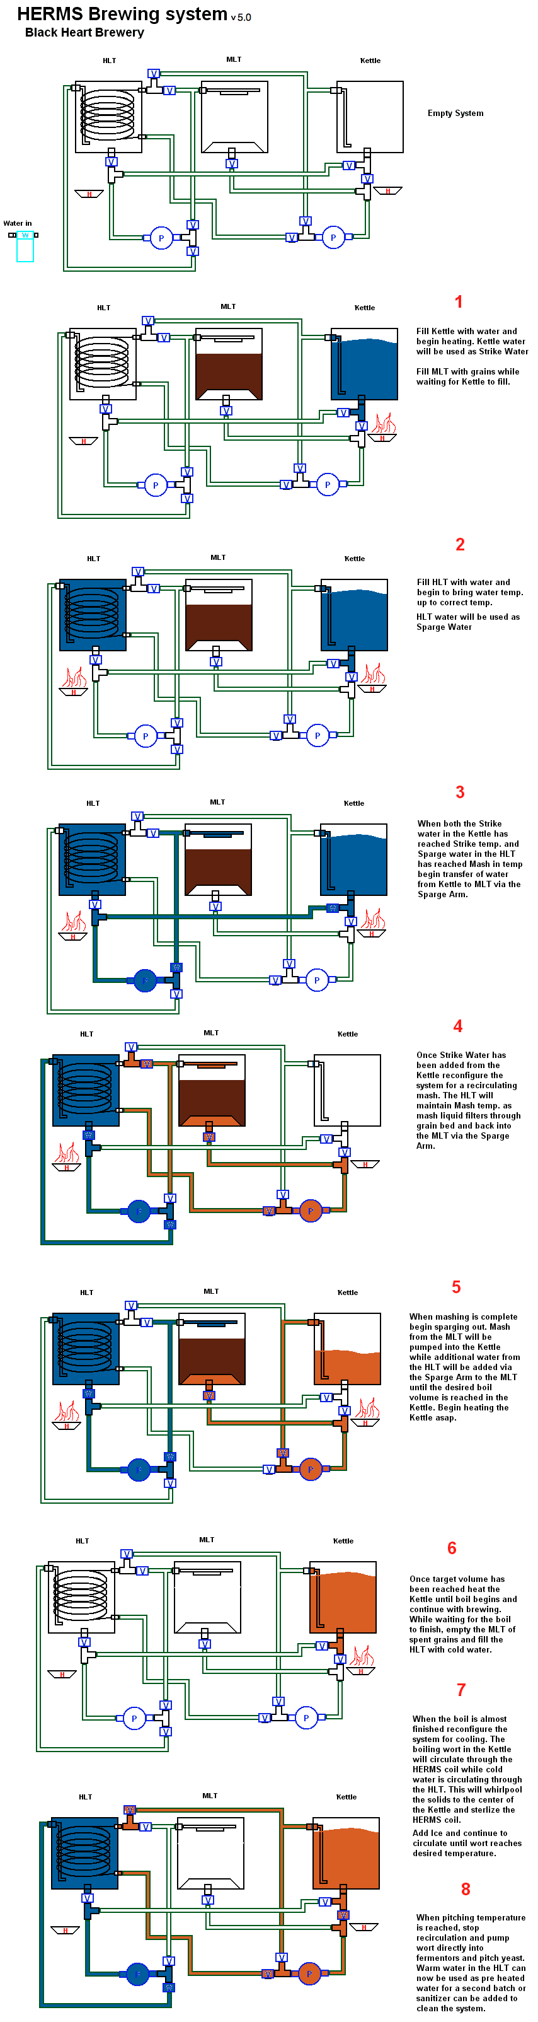
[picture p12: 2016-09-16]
Info/Frame/HERMSv5.png

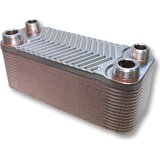
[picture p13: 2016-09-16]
Info/Frame/41DTmfcIecL._AC_UL160_SR160,160_.jpg

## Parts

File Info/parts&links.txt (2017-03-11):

tauchhülse mit klemmverschraubung

Futurashop
3x Temparatursonde 2846-SONDADS18B20 http://www.futurashop.it/sonda-di-temperatura-waterproof-con-ds18b20-2846-sondads18b20
1x Wippschalter 8220-R1944C/G
http://www.futurashop.it/interruttore-con-luce-verde-al-neon-8220-r1944cg?search=INTERRUTTORE
3x Buchse Temperatursonde 6520-CA104
http://www.futurashop.it/connettore-xlr-3p-femmina-6520-ca104?search=XLR
http://www.reichelt.de/XLR-Einbaubuchsen-stecker/XLR-3EB/3/index.html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
http://www.reichelt.de/XLR-Einbaubuchsen-stecker/NEUTRIK-DSS-BR/3/index.html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

3x Stecker Temperatursonde 8220-CA093
http://www.futurashop.it/connettore-maschio-3p-xlr-8220-ca093?search=XLR
http://www.reichelt.de/XLR-3ST-N/3/index.html?&ACTION=3&LA=446&ARTICLE=40793&artnr=XLR+3ST-N&SEARCH=xlr
1x Microusb Adapter 2846-PLUGTOUSB
http://www.futurashop.it/plugtousb_microusb
http://www.reichelt.de/Weiteres-Zubehoer/RPI-MICRO-USB-10/3/index.html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

2x SolidStateRelay ??? http://www.futurashop.it/rel%C3%A8-allo-stato-solido-40-a-3-32-vdc-6168-com13015
http://www.reichelt.de/Solid-State-Relais/RA-2425-D06/3/index.html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

Buchse Netz
http://www.reichelt.de/Kaltgeraeteeinbaustecker/KES-1/3/index.html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

motortreiber
http://www.robotstore.it/product/150/Pololu-TB6612FNG-Dual-Motor-Driver-Carrier.html
http://www.robotstore.it/product/503/DC-Dual-Motor-Driver-30V-4A-V2.html

spannungsregler
http://www.ebay.it/itm/0898-Regolatore-di-tensione-Step-Down-Buck-Regulator-D24V3F5-/351694415824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

1x Netzteil meanwell 5V 3A
http://www.3lco.biz/product.php?id_product=4575
http://www.3lco.biz/product.php?id_product=5377
http://www.3lco.biz/product.php?id_product=7460
http://www.reichelt.de/Schaltnetzteile-bis-150-W/SNT-RS-25-5/3/index.html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

https://www.reichelt.de/Erweiterungsboards/RASP-SHD-PROTO/3/index.html?ACTION=3&GROUPID=6669&ARTICLE=163031

schalter
http://www.reichelt.de/WIPPE-1839-3502/3/index.html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

2x Stecker Magnetventil
2x Buchse Magnetventil
2x Stecker Rührwerk/motor 
http://thumbs2.ebaystatic.com/d/l225/m/mtaVeN_QaZU09iCsxInTt5g.jpg
http://www.reichelt.de/Kaltgeraeteeinbaubuchsen/S-KE4B-Q/3/index.html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

1x Strombuchse http://www.hollandlink.nl/data/articles/images/big/b_49.jpg
1x Sicherungshalter
http://i.ebayimg.com/t/TECCRIS-Sicherungshalter-5-x-20mm-Glas-Fein-Sicherung-Halter-10A-250V-PKW-KFZ-/00/s/NDMyWDY1MA==/z/3asAAOSw~OdVa2-P/$_35.JPG

Sonstiges
3x Fitting Temperatursonde
6x Schrauben M6x50 inox 
6x Mutter Plastik M6
1x Schlitzblech/Lochblech
1x Schaltkasten
1x Pumpe
1x Motor Rührwerk
1x Inverter Pumpe??

Infos
Software:
http://craftbeerpi.com/
http://www.sansalinux.org/mashberry/index.html
http://www.easybrew.it/
http://www.brewpi.com/
http://www.dunkelbrauer.de/Software/
codesys

DIN 11852 Milchverschraubung
http://www.bacbrewing.com/
http://www.mtec-eckerlin.de/
http://www.maremossoforzasette.it/
http://www.polsinelli.it
http://www.watterott.com
http://www.robanautica.it/
http://www.forniturebirra.com/

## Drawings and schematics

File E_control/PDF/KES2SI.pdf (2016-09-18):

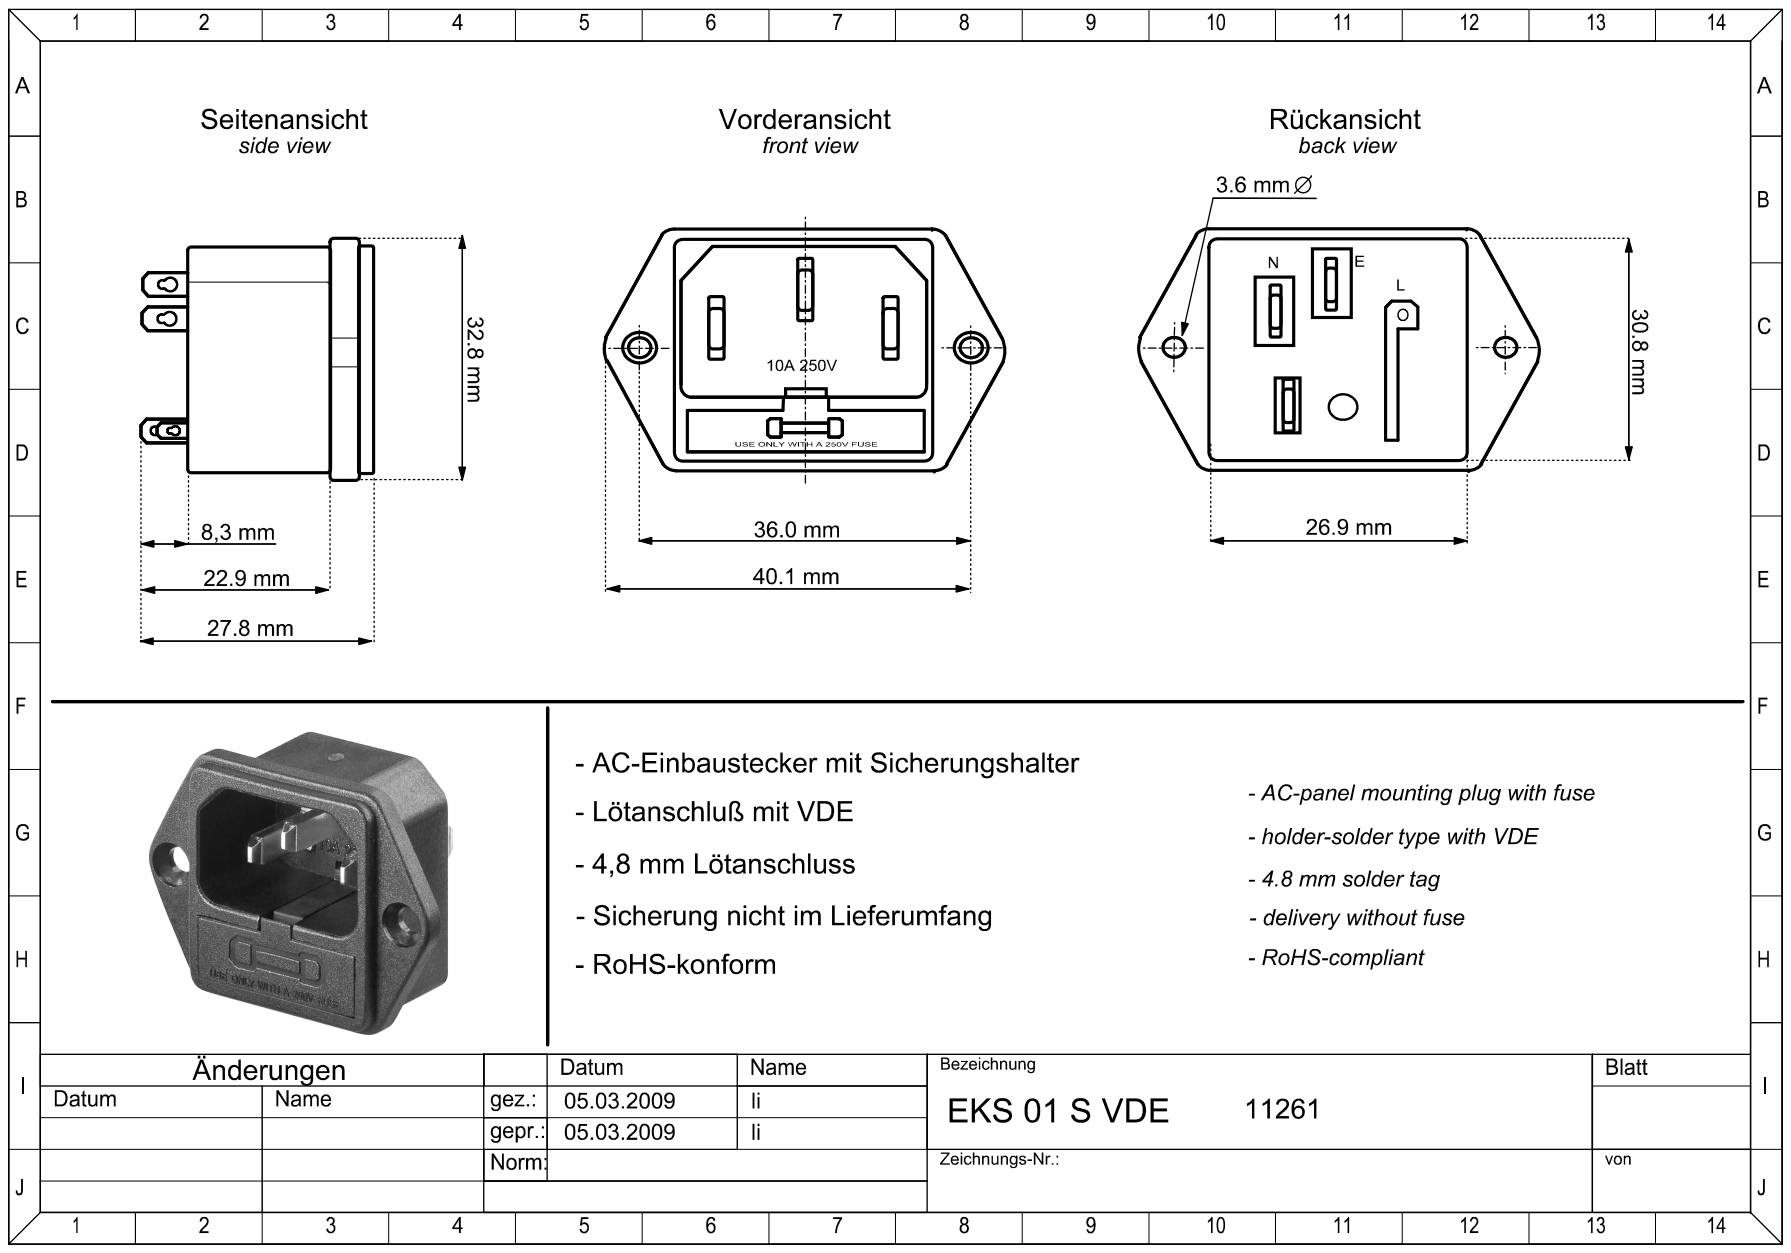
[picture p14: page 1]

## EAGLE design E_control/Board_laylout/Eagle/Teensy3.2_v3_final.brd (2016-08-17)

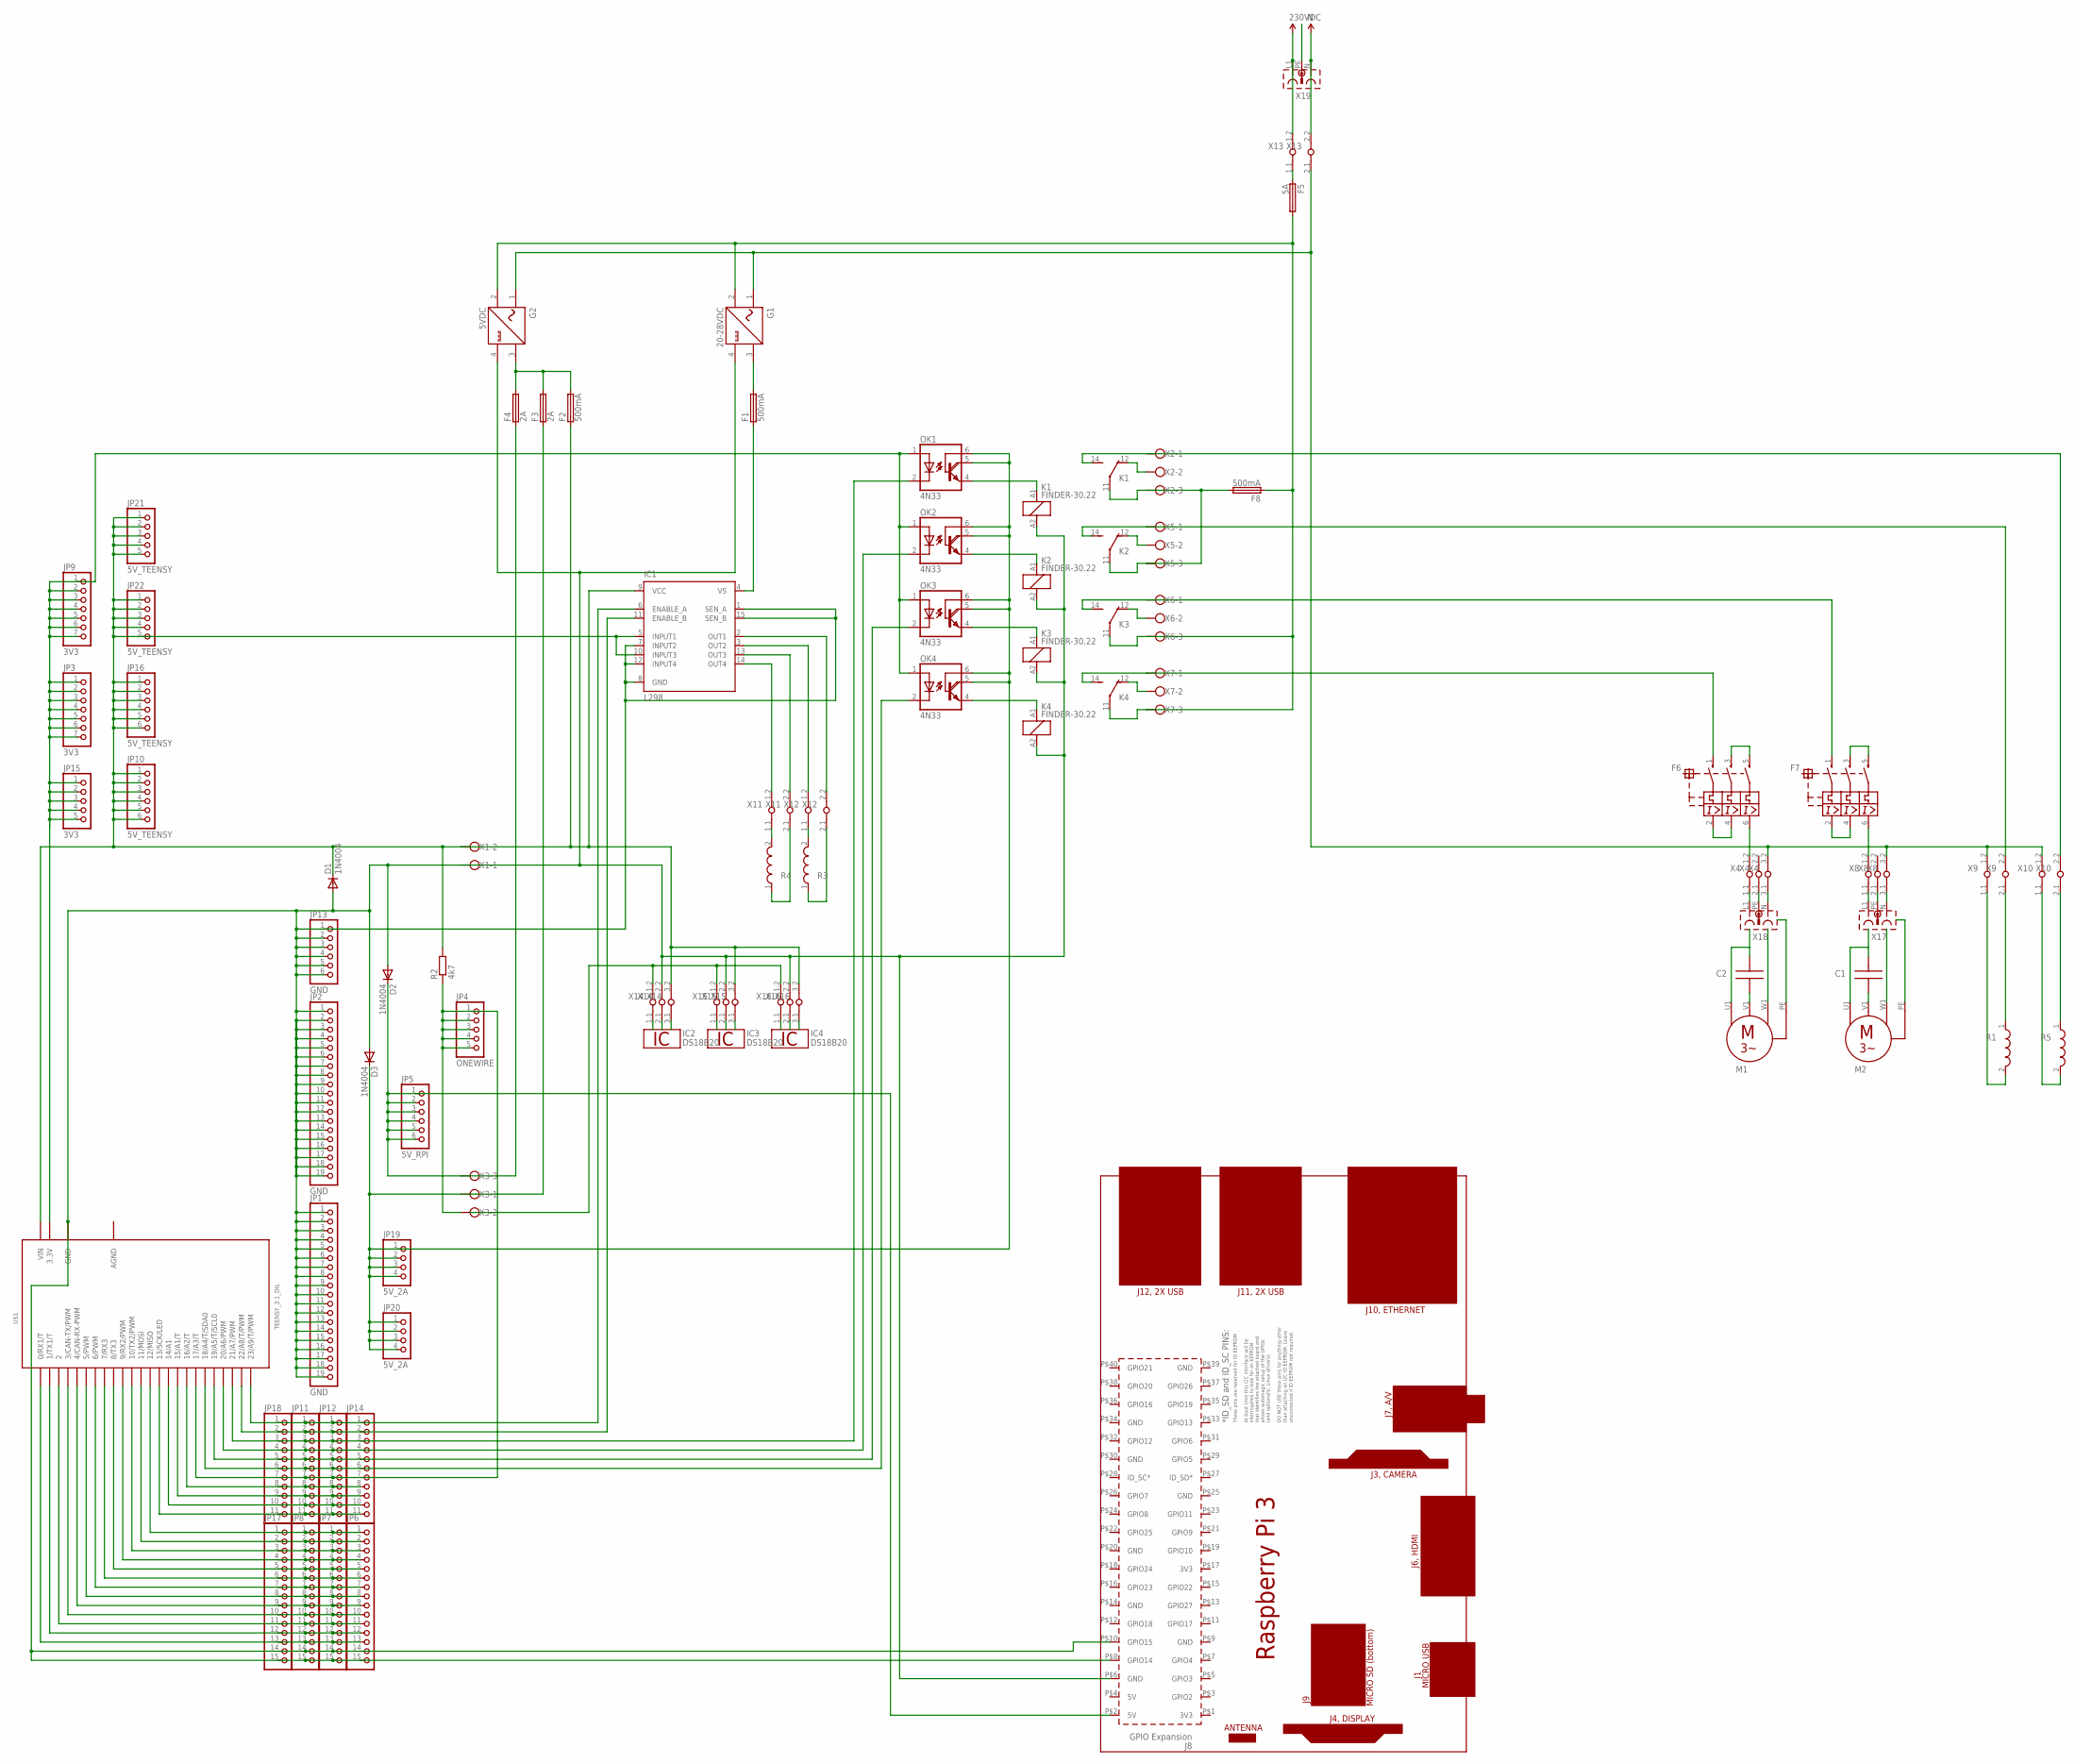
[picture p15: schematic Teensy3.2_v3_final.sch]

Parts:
C1, C2: KONDENSATOR_KAPAZITAET_ALLGEMEIN
D1, D2, D3: 1N4004; DO41-10
F1, F2, F8: 500mA; GSH15
F3, F4: 2A; GSH15
F5: 5A; GSH15
F6, F7: MOTORSCHUTZSCHALTER_3-POL_THERM_MAG_HANDBETAETIGT
G1: 20-28VDC; NETZTEIL_GLEICHSPANNUNG
G2: 5VDC; NETZTEIL_GLEICHSPANNUNG
IC1: L298; MULTIWATT-15
IC2, IC3, IC4: DS18B20; TO92-
JP1, JP2: GND; 1X19
JP3, JP9: 3V3; 1X07
JP4: ONEWIRE; 1X05
JP5: 5V_RPI; 1X06
JP6, JP7, JP8, JP17: PINHD-1X15; 1X15
JP10, JP16: 5V_TEENSY; 1X06
JP11, JP12, JP14, JP18: PINHD-1X11; 1X11
JP13: GND; 1X06
JP15: 3V3; 1X05
JP19, JP20: 5V_2A; 1X04
JP21, JP22: 5V_TEENSY; 1X05
K1, K2, K3, K4: FINDER-30.22
M1, M2: MOTOR_3-POL_PE
OK1, OK2, OK3, OK4: 4N33; DIL06
PCB1: RPI3
R1, R3, R4, R5: SPULE_ALTERNATIV; SPULE
R2: 4k7; 0204/5
U$1: TEENSY_3.1_DIL; TEENSY3-DIL
X1: W237-102
X2, X3, X5, X6, X7: W237-103
X4, X8, X14, X15, X16: KLEMME_1-3
X9, X10, X11, X12, X13: KLEMME_1-2
X17, X18, X19: STECKDOSE

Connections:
0V: D1.A, D2.A, D3.A, G1.4, G2.4, IC1.1 (SEN_A), IC1.7 (INPUT2), IC1.8 (GND), IC1.12 (INPUT4), IC1.15 (SEN_B), JP1.1, JP1.2, JP1.3, JP1.4, JP1.5, JP1.6, JP1.7, JP1.8, JP1.9, JP1.10, JP1.11, JP1.12, JP1.13, JP1.14, JP1.15, JP1.16, JP1.17, JP1.18, JP1.19, JP2.1, JP2.2, JP2.3, JP2.4, JP2.5, JP2.6, JP2.7, JP2.8, JP2.9, JP2.10, JP2.11, JP2.12, JP2.13, JP2.14, JP2.15, JP2.16, JP2.17, JP2.18, JP2.19, JP6.14, JP6.15, JP7.14, JP7.15, JP8.14, JP8.15, JP13.1, JP13.2, JP13.3, JP13.4, JP13.5, JP13.6, JP17.14, JP17.15, K1.A2 (2), K2.A2 (2), K3.A2 (2), K4.A2 (2), PCB1.P$6 (GND), PCB1.P$8 (GPIO14), PCB1.P$10 (GPIO15), U$1.GND, X1.1, X14.2.2, X15.2.2, X16.2.2
1W: IC2.2 (1W), IC3.2 (1W), IC4.2 (1W)
5V_0,5A: D1.C, F2.1, IC1.5 (INPUT1), IC1.9 (VCC), IC1.10 (INPUT3), JP10.1, JP10.2, JP10.3, JP10.4, JP10.5, JP10.6, JP16.1, JP16.2, JP16.3, JP16.4, JP16.5, JP16.6, JP21.1, JP21.2, JP21.3, JP21.4, JP21.5, JP22.1, JP22.2, JP22.3, JP22.4, JP22.5, R2.2, U$1.VIN, X1.2, X14.3.2, X15.3.2, X16.3.2
5V_1A: D3.C, F3.1, JP19.1, JP19.2, JP19.3, JP19.4, JP20.1, JP20.2, JP20.3, JP20.4, OK1.5 (COL), OK1.6 (B), OK2.5 (COL), OK2.6 (B), OK3.5 (COL), OK3.6 (B), OK4.5 (COL), OK4.6 (B), X3.1
5V_2A: D2.C, F4.1, JP5.1, JP5.2, JP5.3, JP5.4, JP5.5, JP5.6, PCB1.P$2 (5V), X3.3
AGND: U$1.AGND
GND: IC2.1 (GND), IC3.1 (GND), IC4.1 (GND)
unnamed: JP4.1, JP4.2, JP4.3, JP4.4, JP4.5, JP11.7, JP12.7, JP14.7, JP18.7, R2.1, U$1.17/A3 (17/A3/T), X3.2
unnamed: F8.2, K1.11, K2.11, X2.3, X5.3
unnamed: R4.2, X11.1.1
unnamed: JP6.13, JP7.13, JP8.13, JP17.13, U$1.0 (0/RX1/T)
unnamed: X14.1.2, X15.1.2, X16.1.2
unnamed: JP6.11, JP7.11, JP8.11, JP17.11, U$1.2
unnamed: JP6.10, JP7.10, JP8.10, JP17.10, U$1.3 (3/CAN-TX/PWM)
unnamed: JP6.9, JP7.9, JP8.9, JP17.9, U$1.4 (4/CAN-RX-PWM)
unnamed: JP6.8, JP7.8, JP8.8, JP17.8, U$1.5 (5/PWM)
unnamed: JP6.7, JP7.7, JP8.7, JP17.7, U$1.6 (6/PWM)
unnamed: JP6.6, JP7.6, JP8.6, JP17.6, U$1.7 (7/RX3)
unnamed: JP6.5, JP7.5, JP8.5, JP17.5, U$1.8 (8/TX3)
unnamed: JP6.4, JP7.4, JP8.4, JP17.4, U$1.9 (9/RX2/PWM)
unnamed: JP6.3, JP7.3, JP8.3, JP17.3, U$1.10 (10/TX2/PWM)
unnamed: JP6.2, JP7.2, JP8.2, JP17.2, U$1.11 (11/MOSI)
unnamed: R4.1, X11.2.1
unnamed: JP6.1, JP7.1, JP8.1, JP17.1, U$1.12 (12/MISO)
unnamed: JP11.11, JP12.11, JP14.11, JP18.11, U$1.13 (13/SCK/LED)
unnamed: JP11.10, JP12.10, JP14.10, JP18.10, U$1.14/A0 (14/A1)
unnamed: JP11.9, JP12.9, JP14.9, JP18.9, U$1.15/A1 (15/A1/T)
unnamed: JP11.8, JP12.8, JP14.8, JP18.8, U$1.16/A2 (16/A2/T)
unnamed: F1.2, G1.3
unnamed: JP11.6, JP12.6, JP14.6, JP18.6, OK4.2 (C), U$1.18/A4 (18/A4/T/SDA0)
unnamed: R3.2, X12.1.1
unnamed: JP11.5, JP12.5, JP14.5, JP18.5, OK3.2 (C), U$1.19/A5 (19/A5/T/SCL0)
unnamed: JP11.4, JP12.4, JP14.4, JP18.4, OK2.2 (C), U$1.20/A6 (20/A6/PWM)
unnamed: JP11.3, JP12.3, JP14.3, JP18.3, OK1.2 (C), U$1.21/A7 (21/A7/PWM)
unnamed: IC1.11 (ENABLE_B), JP11.2, JP12.2, JP14.2, JP18.2, U$1.22/A8 (22/A8/T/PWM)
unnamed: IC1.6 (ENABLE_A), JP11.1, JP12.1, JP14.1, JP18.1, U$1.23/A9 (23/A9/T/PWM)
unnamed: K1.A1 (1), OK1.4 (E)
unnamed: JP6.12, JP7.12, JP8.12, JP17.12, U$1.1 (1/TX1/T)
unnamed: JP3.1, JP3.2, JP3.3, JP3.4, JP3.5, JP3.6, JP3.7, JP9.1, JP9.2, JP9.3, JP9.4, JP9.5, JP9.6, JP9.7, JP15.1, JP15.2, JP15.3, JP15.4, JP15.5, OK1.1 (A), OK2.1 (A), OK3.1 (A), OK4.1 (A), U$1.3.3V
unnamed: R3.1, X12.2.1
unnamed: F5.1, X13.1.1
unnamed: K1.12 (O), X2.2
unnamed: F5.2, F8.1, G1.2, G2.2, K3.11, K4.11, X6.3, X7.3
unnamed: F6.2, F6.4
unnamed: K4.A1 (1), OK4.4 (E)
unnamed: K3.A1 (1), OK3.4 (E)
unnamed: K2.A1 (1), OK2.4 (E)
unnamed: F6.3, F6.5
unnamed: F6.6, X4.1.2
unnamed: F6.1, F7.1, K2.14 (S), X5.1, X9.2.2
unnamed: K2.12 (O), X5.2
unnamed: F7.2, F7.4
unnamed: K3.14 (S), X6.1
unnamed: K3.12 (O), X6.2
unnamed: F7.3, F7.5
unnamed: K4.14 (S), X7.1
unnamed: K4.12 (O), X7.2
unnamed: X4.1.1, X18.L1
unnamed: C2.2, M1.V1
unnamed: C1.2, M2.V1
unnamed: K1.14 (S), X2.1, X10.2.2
unnamed: C2.1, M1.U1
unnamed: X4.2.1, X18.PE
unnamed: C1.1, M2.U1
unnamed: X4.3.1, X18.N
unnamed: R1.2, X9.1.1
unnamed: R1.1, X9.2.1
unnamed: R5.2, X10.1.1
unnamed: R5.1, X10.2.1
unnamed: X8.3.1, X17.N
unnamed: X8.1.1, X17.L1
unnamed: IC1.13 (OUT3), X11.2.2
unnamed: IC1.2 (OUT1), X12.2.2
unnamed: G1.1, G2.1, X4.3.2, X8.3.2, X9.1.2, X10.1.2, X13.2.1
unnamed: F1.1, IC1.4 (VS)
unnamed: F2.2, F3.2, F4.2, G2.3
unnamed: F7.6, X8.1.2
unnamed: X8.2.1, X17.PE
VCC: X13.1.2, X13.2.2, X19.L1, X19.N
VDD: IC2.3 (VDD), IC3.3 (VDD), IC4.3 (VDD)

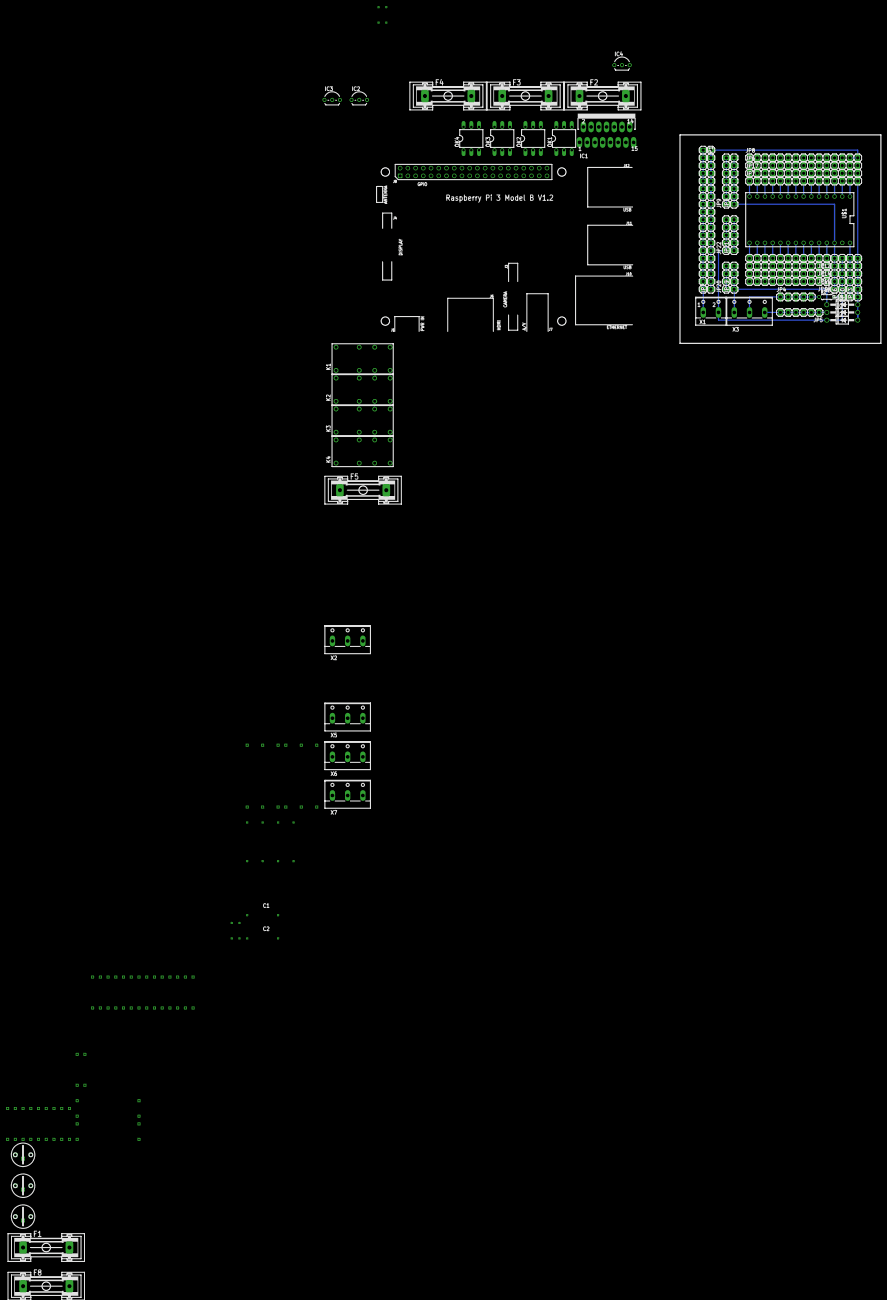
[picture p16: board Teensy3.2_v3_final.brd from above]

Board: 2 copper layers, 66.0 x 68.5 mm, 77 parts (0 on the bottom side), 79 nets.

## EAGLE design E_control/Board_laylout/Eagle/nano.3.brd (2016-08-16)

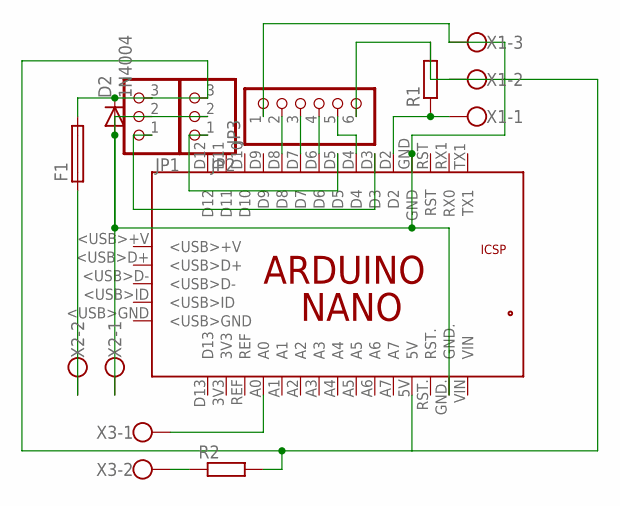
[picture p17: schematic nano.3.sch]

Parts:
D2: 1N4004; DO41-10
F1: GSH15
JP1, JP2: PINHD-1X3; 1X03
JP3: PINHD-1X6; 1X06
PCB2: ARDUINO_NANO
R1: R-EU_0207/15; 0207/15
R2: R-EU_0204/7; 0204/7
X1: W237-103
X2, X3: W237-102

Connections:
unnamed: D2.C, F1.2, JP1.3, JP2.3, JP3.6, PCB2.5V, R1.2, R2.2, X1.2
unnamed: D2.A, JP1.2, JP2.2, JP3.1, PCB2.GND, PCB2.GND., X1.3, X2.1
unnamed: R2.1, X3.2
unnamed: PCB2.A0, X3.1
unnamed: JP3.2, PCB2.D8
unnamed: JP3.3, PCB2.D7
unnamed: JP3.4, PCB2.D6
unnamed: JP3.5, PCB2.D4
unnamed: JP2.1, PCB2.D5
unnamed: PCB2.D2, R1.1, X1.1
unnamed: JP1.1, PCB2.D3
unnamed: F1.1, X2.2

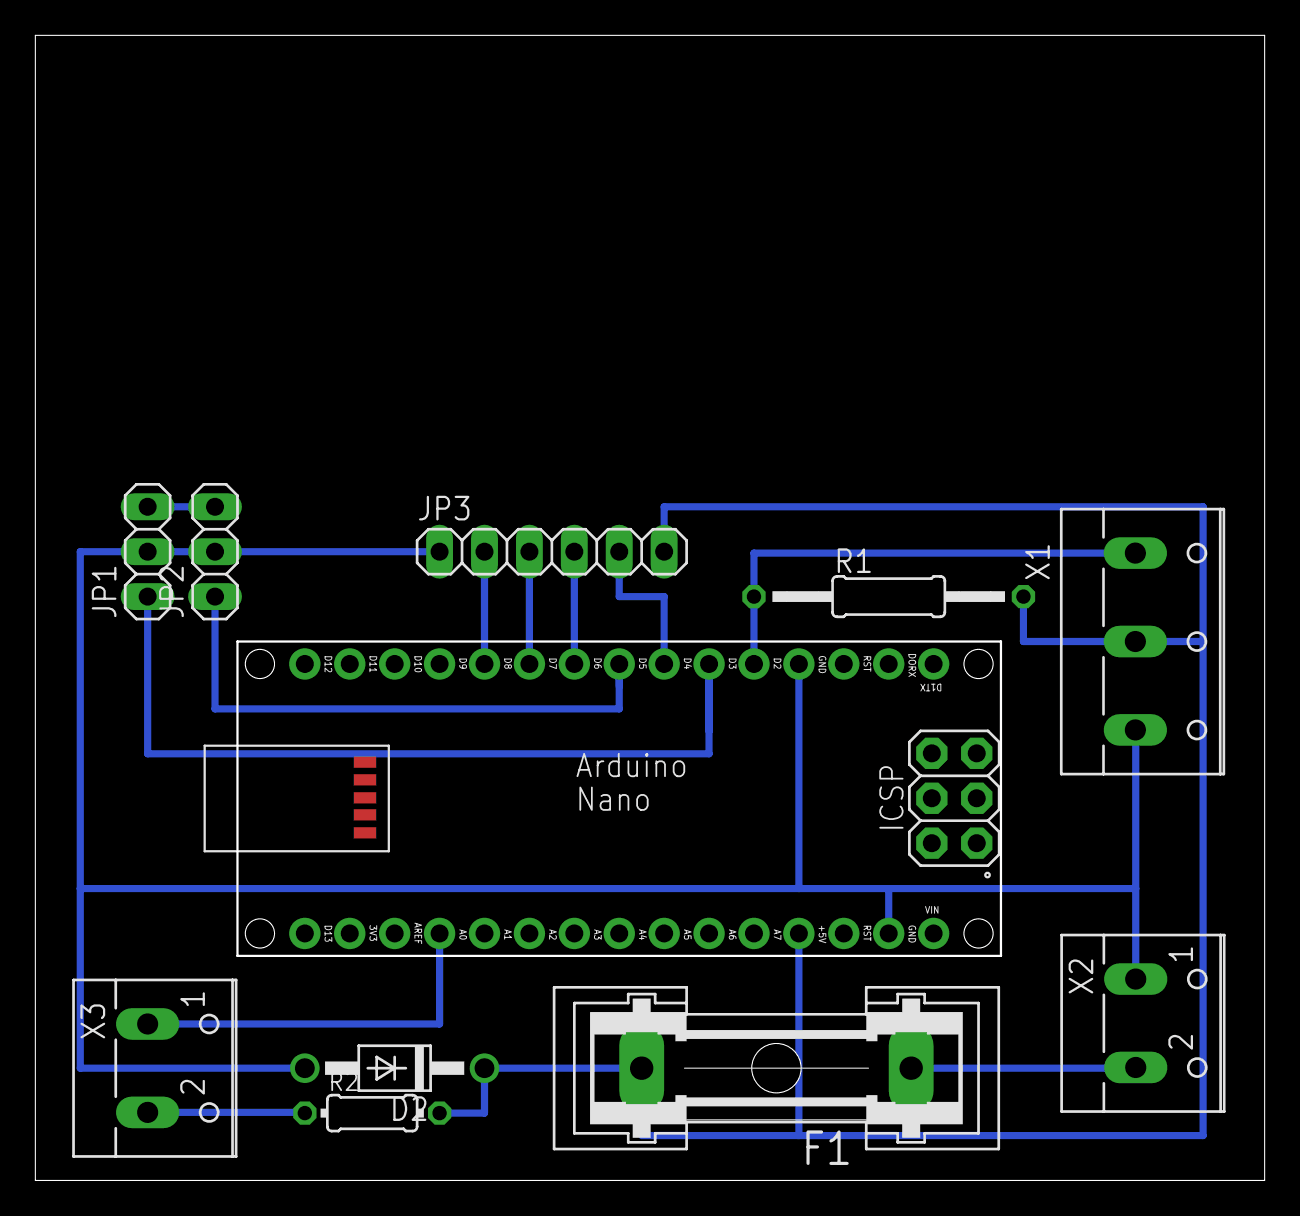
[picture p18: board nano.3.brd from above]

Board: 2 copper layers, 69.5 x 64.8 mm, 11 parts (0 on the bottom side), 12 nets.

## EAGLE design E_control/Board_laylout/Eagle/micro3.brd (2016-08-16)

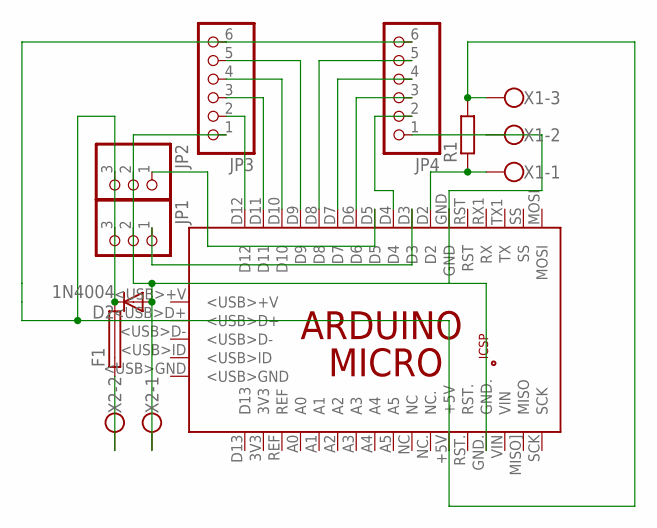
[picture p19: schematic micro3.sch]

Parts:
D2: 1N4004; DO41-10
F1: GSH15
JP1, JP2: PINHD-1X3; 1X03
JP3, JP4: PINHD-1X6; 1X06
PCB1: ARDUINO_MICRO
R1: R-EU_0207/15; 0207/15
X1: W237-103
X2: W237-102

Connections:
unnamed: JP3.2, PCB1.D12
unnamed: JP3.3, PCB1.D11
unnamed: JP3.4, PCB1.D10
unnamed: JP3.5, PCB1.D9
unnamed: JP4.5, PCB1.D8
unnamed: JP4.4, PCB1.D7
unnamed: JP4.3, PCB1.D6
unnamed: JP4.2, PCB1.D4
unnamed: JP2.1, PCB1.D5
unnamed: PCB1.D2, R1.1, X1.1
unnamed: JP1.1, PCB1.D3
unnamed: D2.C, F1.2, JP1.3, JP2.3, JP3.6, JP4.6, PCB1.+5V, R1.2, X1.3
unnamed: F1.1, X2.2
unnamed: D2.A, JP1.2, JP2.2, JP3.1, JP4.1, PCB1.GND, PCB1.GND., X1.2, X2.1

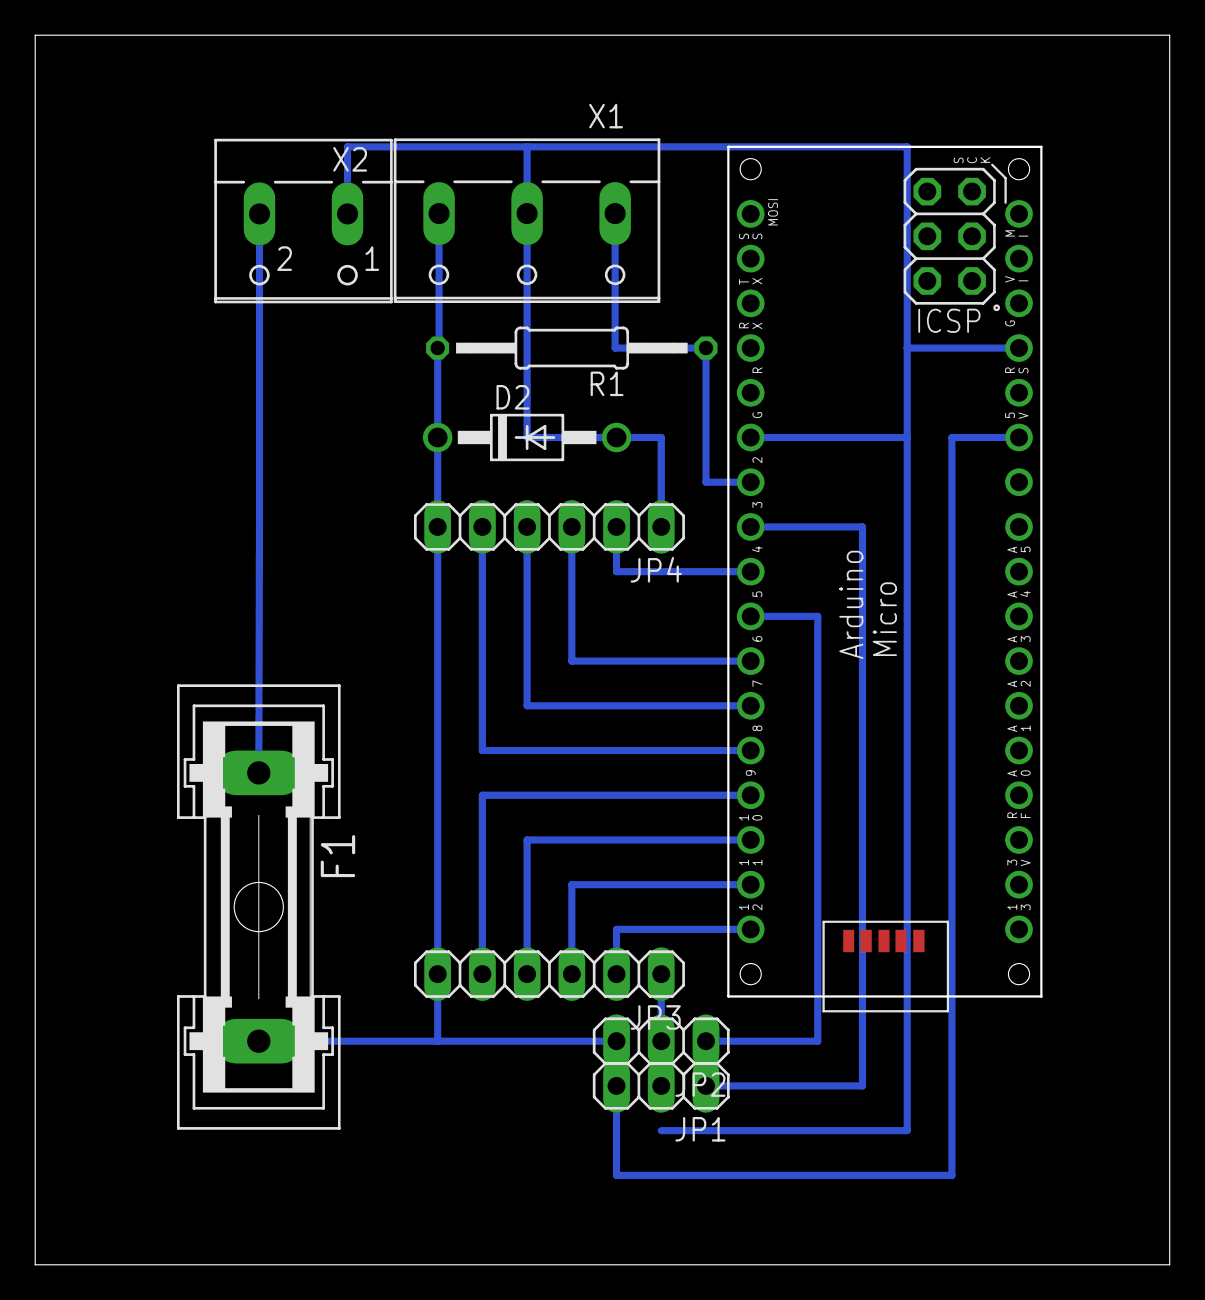
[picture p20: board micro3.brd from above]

Board: 2 copper layers, 64.4 x 69.8 mm, 10 parts (0 on the bottom side), 14 nets.

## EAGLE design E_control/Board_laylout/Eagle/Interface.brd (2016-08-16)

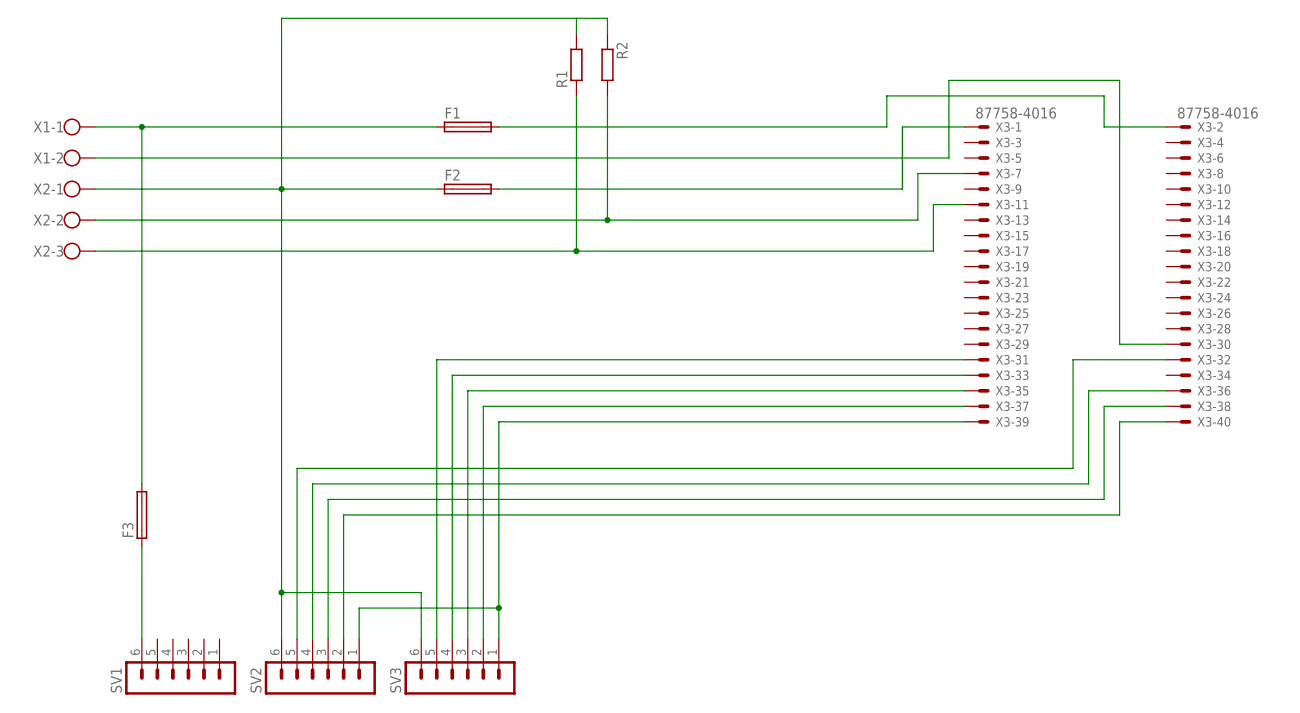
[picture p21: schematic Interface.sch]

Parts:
F1, F2, F3: GSH15
R1: R-EU_0207/10; 0207/10
R2: R-EU_0207/5V; 0207/5V
SV1, SV2, SV3: MA06-1
X1: W237-102
X2: W237-103
X3: 87758-4016

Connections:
unnamed: F1.1, F3.2, X1.1
unnamed: F2.1, R1.2, R2.1, SV2.6, SV3.6, X2.1
unnamed: F3.1, SV1.6
unnamed: X1.2, X3.30
unnamed: R2.2, X2.2, X3.7
unnamed: R1.1, X2.3, X3.11
unnamed: SV2.5, X3.32
unnamed: SV2.4, X3.36
unnamed: SV2.3, X3.38
unnamed: SV2.2, X3.40
unnamed: SV3.2, X3.37
unnamed: SV3.3, X3.35
unnamed: SV3.4, X3.33
unnamed: SV3.5, X3.31
unnamed: F2.2, X3.1
unnamed: F1.2, X3.2
unnamed: SV2.1, SV3.1, X3.39

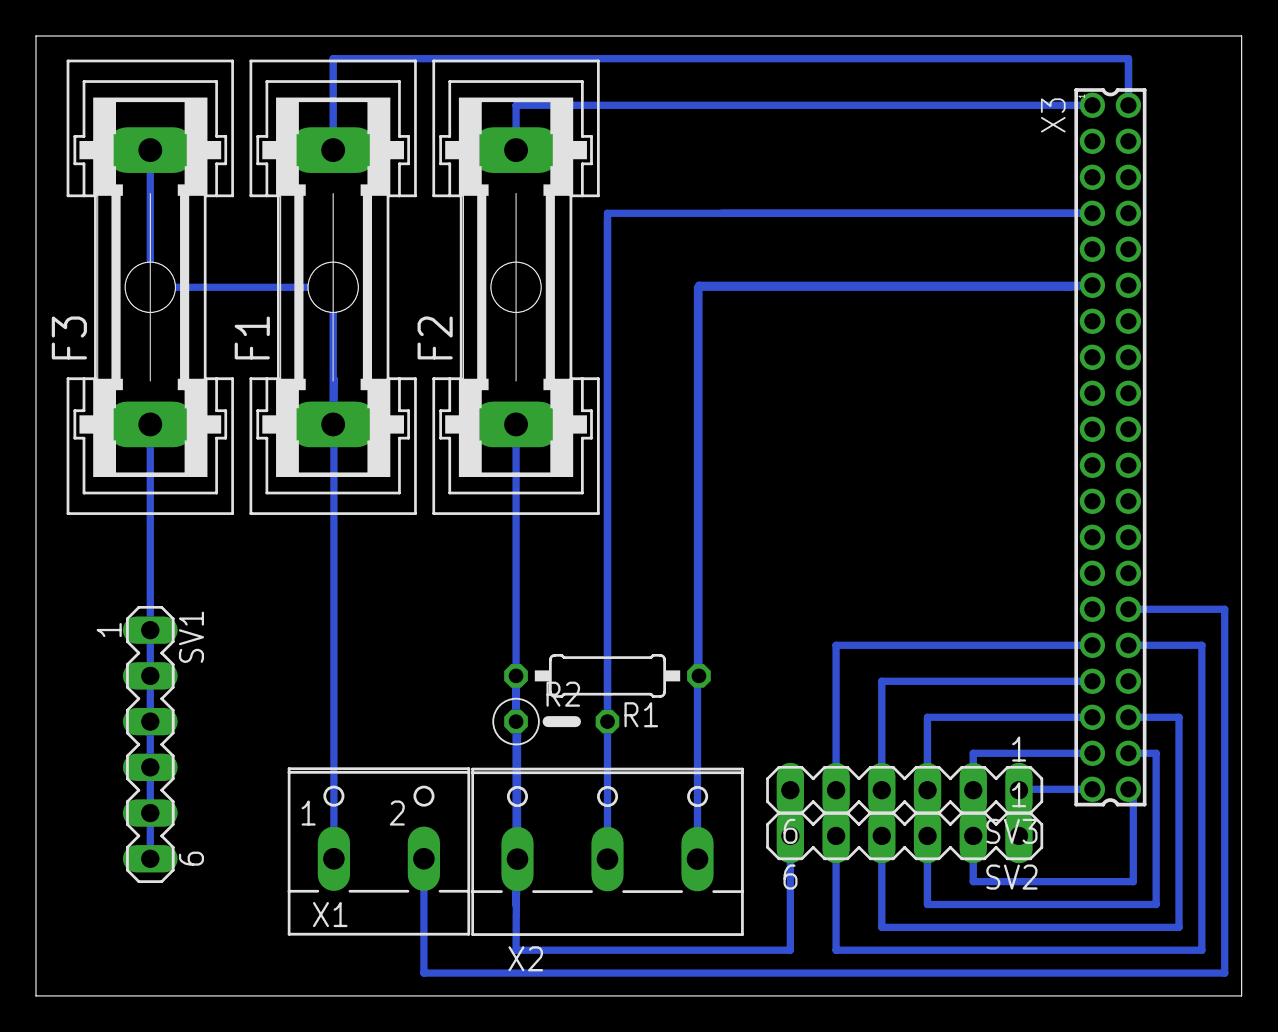
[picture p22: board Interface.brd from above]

Board: 2 copper layers, 67.0 x 53.3 mm, 11 parts (0 on the bottom side), 17 nets.

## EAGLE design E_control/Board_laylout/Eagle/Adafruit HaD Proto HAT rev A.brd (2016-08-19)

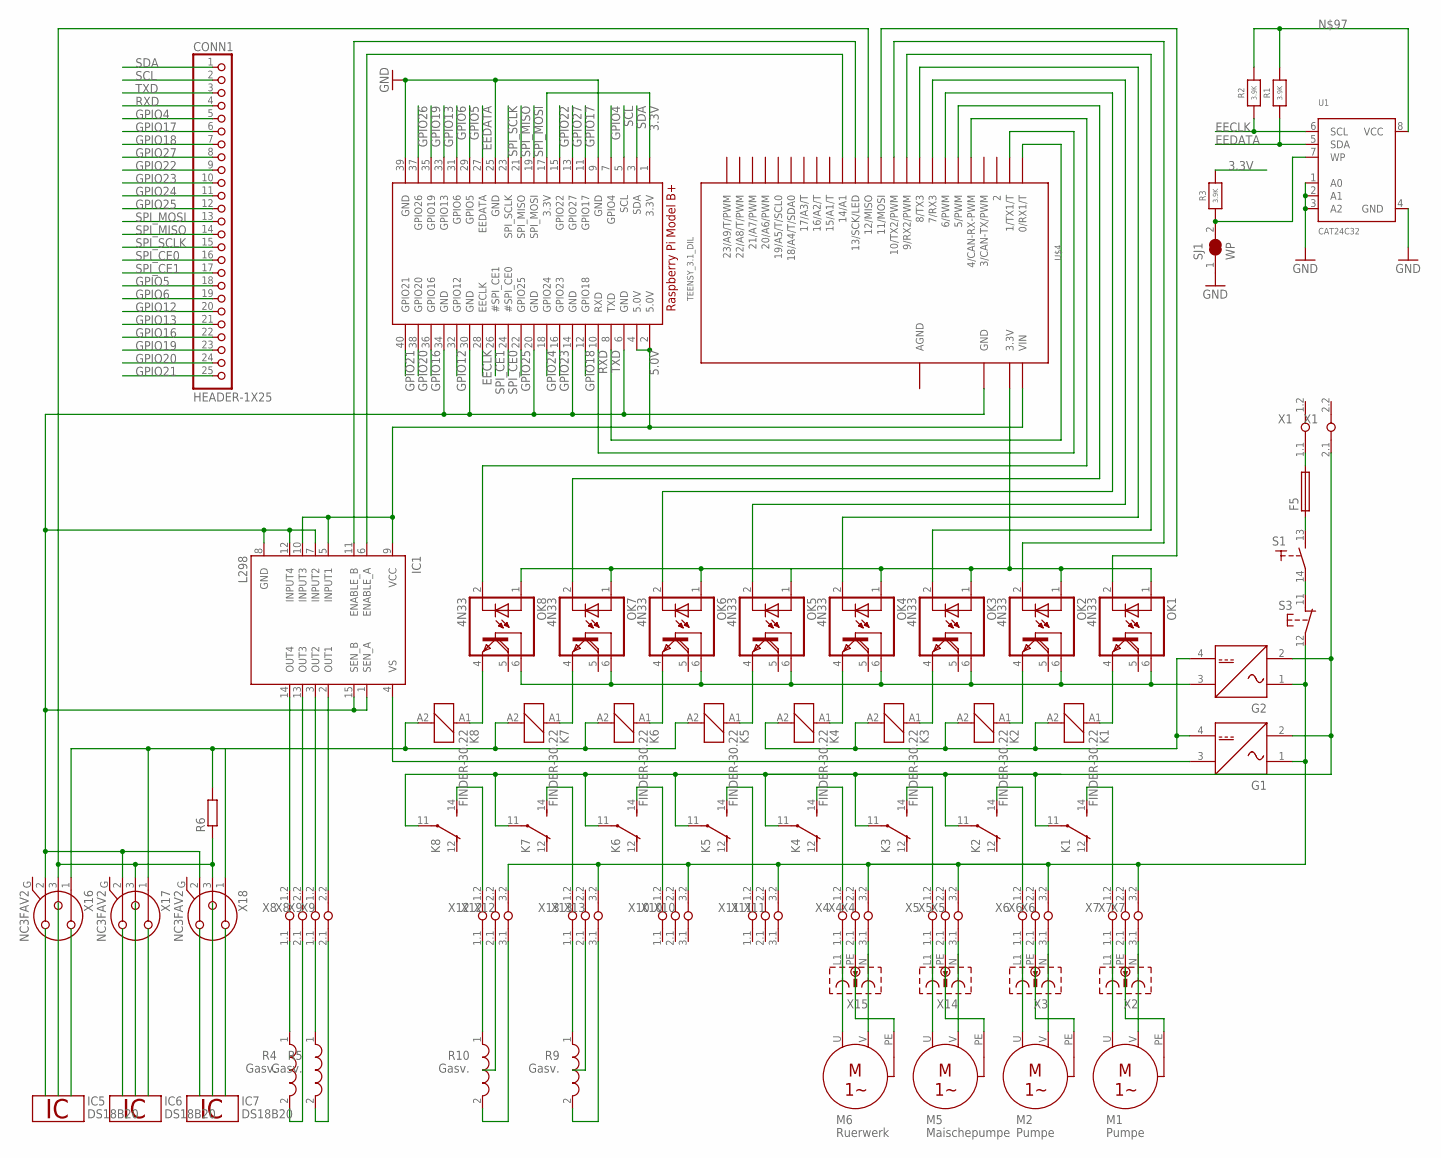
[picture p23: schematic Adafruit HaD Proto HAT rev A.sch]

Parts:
CONN1: HEADER-1X25; 1X25_ROUND_70MIL
F5: KS9V
G1, G2: NETZTEIL_GLEICHSPANNUNG
IC1: L298; MULTIWATT-15
IC5, IC6, IC7: DS18B20; TO92-
K1, K2, K3, K4, K5, K6, K7, K8: FINDER-30.22
M1, M2: Pumpe; MOTOR_1-PHASEN
M5: Maischepumpe; MOTOR_1-PHASEN
M6: Ruerwerk; MOTOR_1-PHASEN
OK1, OK2, OK3, OK4, OK5, OK6, OK7, OK8: 4N33; DIL06
R1, R2, R3: 3.9K; 0805-NO
R4, R5, R9, R10: Gasv.; SPULE
R6: R-EU_0204/2V; 0204V
RPI1: RASPBERRYPI_BPLUS_HATNOSLOTS; PI_HAT_NOSLOTS
S1: SCHLIESSER_KIPPSCHALTER
S3: TASTER_OEFFNER; AUSTASTER
SJ1: WP; SOLDERJUMPER_CLOSEDWIRE
U1: CAT24C32; SOIC8_150MIL
U$4: TEENSY_3.1_DIL; TEENSY3-DIL
X1, X8, X9: KLEMME_1-2
X2, X3, X14, X15: STECKDOSE
X4, X5, X6, X7, X10, X11, X12, X13: KLEMME_1-3
X16, X17, X18: NC3FAV2

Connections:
1W: IC5.2 (1W), IC6.2 (1W), IC7.2 (1W)
3.3V: R3.2, RPI1.1 (3.3V), RPI1.17 (3.3V)
5.0V: IC1.5 (INPUT1), IC1.9 (VCC), IC1.10 (INPUT3), RPI1.2 (5.0V), RPI1.4 (5.0V), U$4.VIN
AGND: U$4.AGND
EECLK: R2.1, RPI1.28 (EECLK), U1.6 (SCL)
EEDATA: R1.1, RPI1.27 (EEDATA), U1.5 (SDA)
GND: IC1.1 (SEN_A), IC1.7 (INPUT2), IC1.8 (GND), IC1.12 (INPUT4), IC1.15 (SEN_B), IC5.1 (GND), IC6.1 (GND), IC7.1 (GND), RPI1.6 (GND), RPI1.9 (GND), RPI1.14 (GND), RPI1.20 (GND), RPI1.25 (GND), RPI1.30 (GND), RPI1.34 (GND), RPI1.39 (GND), SJ1.1, U1.1 (A0), U1.2 (A1), U1.3 (A2), U1.4 (GND), U$4.GND, X16.2, X17.2, X18.2
GPIO4: CONN1.5, RPI1.7 (GPIO4)
GPIO5: CONN1.18, RPI1.29 (GPIO5)
GPIO6: CONN1.19, RPI1.31 (GPIO6)
GPIO12: CONN1.20, RPI1.32 (GPIO12)
GPIO13: CONN1.21, RPI1.33 (GPIO13)
GPIO16: CONN1.22, RPI1.36 (GPIO16)
GPIO17: CONN1.6, RPI1.11 (GPIO17)
GPIO18: CONN1.7, RPI1.12 (GPIO18)
GPIO19: CONN1.23, RPI1.35 (GPIO19)
GPIO20: CONN1.24, RPI1.38 (GPIO20)
GPIO21: CONN1.25, RPI1.40 (GPIO21)
GPIO22: CONN1.9, RPI1.15 (GPIO22)
GPIO23: CONN1.10, RPI1.16 (GPIO23)
GPIO24: CONN1.11, RPI1.18 (GPIO24)
GPIO25: CONN1.12, RPI1.22 (GPIO25)
GPIO26: RPI1.37 (GPIO26)
GPIO27: CONN1.8, RPI1.13 (GPIO27)
unnamed: R3.1, SJ1.2, U1.7 (WP)
unnamed: IC1.11 (ENABLE_B), U$4.13 (13/SCK/LED)
unnamed: IC1.6 (ENABLE_A), U$4.14/A0 (14/A1)
unnamed: IC1.14 (OUT4), X8.1.2
unnamed: G1.3, IC1.4 (VS)
unnamed: G1.1, G1.2, G2.1, G2.2, S3.12 (2), X1.2.1, X4.3.2, X5.3.2, X6.3.2, X7.3.2, X10.3.2, X11.3.2, X12.3.2, X13.3.2
unnamed: R4.2, X8.2.1
unnamed: IC1.3 (OUT2), X9.1.2
unnamed: IC1.2 (OUT1), X9.2.2
unnamed: IC1.13 (OUT3), X8.2.2
unnamed: OK4.2 (C), U$4.8 (8/TX3)
unnamed: OK3.2 (C), U$4.9 (9/RX2/PWM)
unnamed: OK2.2 (C), U$4.10 (10/TX2/PWM)
unnamed: OK1.2 (C), U$4.11 (11/MOSI)
unnamed: G2.3, OK1.6 (B), OK2.6 (B), OK3.6 (B), OK4.6 (B), OK5.6 (B), OK6.6 (B), OK7.6 (B), OK8.6 (B)
unnamed: K1.A1 (1), OK1.4 (E)
unnamed: K2.A1 (1), OK2.4 (E)
unnamed: K3.A1 (1), OK3.4 (E)
unnamed: K4.A1 (1), OK4.4 (E)
unnamed: M1.U, X2.L1, X7.1.1
unnamed: M2.U, X3.L1, X6.1.1
unnamed: K3.14 (S), X5.1.2
unnamed: K4.14 (S), X4.1.2
unnamed: M5.U, X5.1.1, X14.L1
unnamed: M6.U, X4.1.1, X15.L1
unnamed: K2.14 (S), X6.1.2
unnamed: M2.V, X3.N, X6.3.1
unnamed: K1.14 (S), X7.1.2
unnamed: M1.V, X2.N, X7.3.1
unnamed: X3.PE, X6.2.1
unnamed: X2.PE, X7.2.1
unnamed: M6.V, X4.3.1, X15.N
unnamed: M5.V, X5.3.1, X14.N
unnamed: R4.1, X8.1.1
unnamed: F5.2, X1.1.1
unnamed: F5.1, S1.13 (3)
unnamed: S1.14 (4), S3.11 (1)
unnamed: R6.1, U$4.12 (12/MISO), X16.3, X17.3, X18.3
unnamed: G1.4, G2.4, K1.A2 (2), K2.A2 (2), K3.A2 (2), K4.A2 (2)
unnamed: OK8.2 (C), U$4.4 (4/CAN-RX-PWM)
unnamed: OK7.2 (C), U$4.5 (5/PWM)
unnamed: OK6.2 (C), U$4.6 (6/PWM)
unnamed: OK5.2 (C), U$4.7 (7/RX3)
unnamed: R1.2, R2.2, U1.8 (VCC)
unnamed: K5.A1 (1), OK5.4 (E)
unnamed: K6.A1 (1), OK6.4 (E)
unnamed: K7.A1 (1), OK7.4 (E)
unnamed: K8.A1 (1), OK8.4 (E)
unnamed: R5.1, X9.1.1
unnamed: R5.2, X9.2.1
unnamed: K7.14 (S), X13.1.2
unnamed: K8.14 (S), X12.1.2
unnamed: K5.A2 (2), K6.A2 (2), K7.A2 (2), K8.A2 (2), R6.2, X16.1, X17.1, X18.1
unnamed: R9.1, X13.1.1
unnamed: R9.2, X13.3.1
unnamed: R10.2, X12.3.1
unnamed: R10.1, X12.1.1
unnamed: K6.14 (S), X10.1.2
unnamed: K5.14 (S), X11.1.2
unnamed: X4.2.1, X15.PE
unnamed: X5.2.1, X14.PE
unnamed: OK1.1 (A), OK2.1 (A), OK3.1 (A), OK4.1 (A), OK5.1 (A), OK6.1 (A), OK7.1 (A), OK8.1 (A), U$4.3.3V
RXD: CONN1.4, RPI1.10 (RXD), U$4.1 (1/TX1/T)
SCL: CONN1.2, RPI1.5 (SCL)
SDA: CONN1.1, RPI1.3 (SDA)
SPI_CE0: CONN1.16, RPI1.24 (#SPI_CE0)
SPI_CE1: CONN1.17, RPI1.26 (#SPI_CE1)
SPI_MISO: CONN1.14, RPI1.21 (SPI_MISO)
SPI_MOSI: CONN1.13, RPI1.19 (SPI_MOSI)
SPI_SCLK: CONN1.15, RPI1.23 (SPI_SCLK)
TXD: CONN1.3, RPI1.8 (TXD), U$4.0 (0/RX1/T)
VDD: IC5.3 (VDD), IC6.3 (VDD), IC7.3 (VDD)

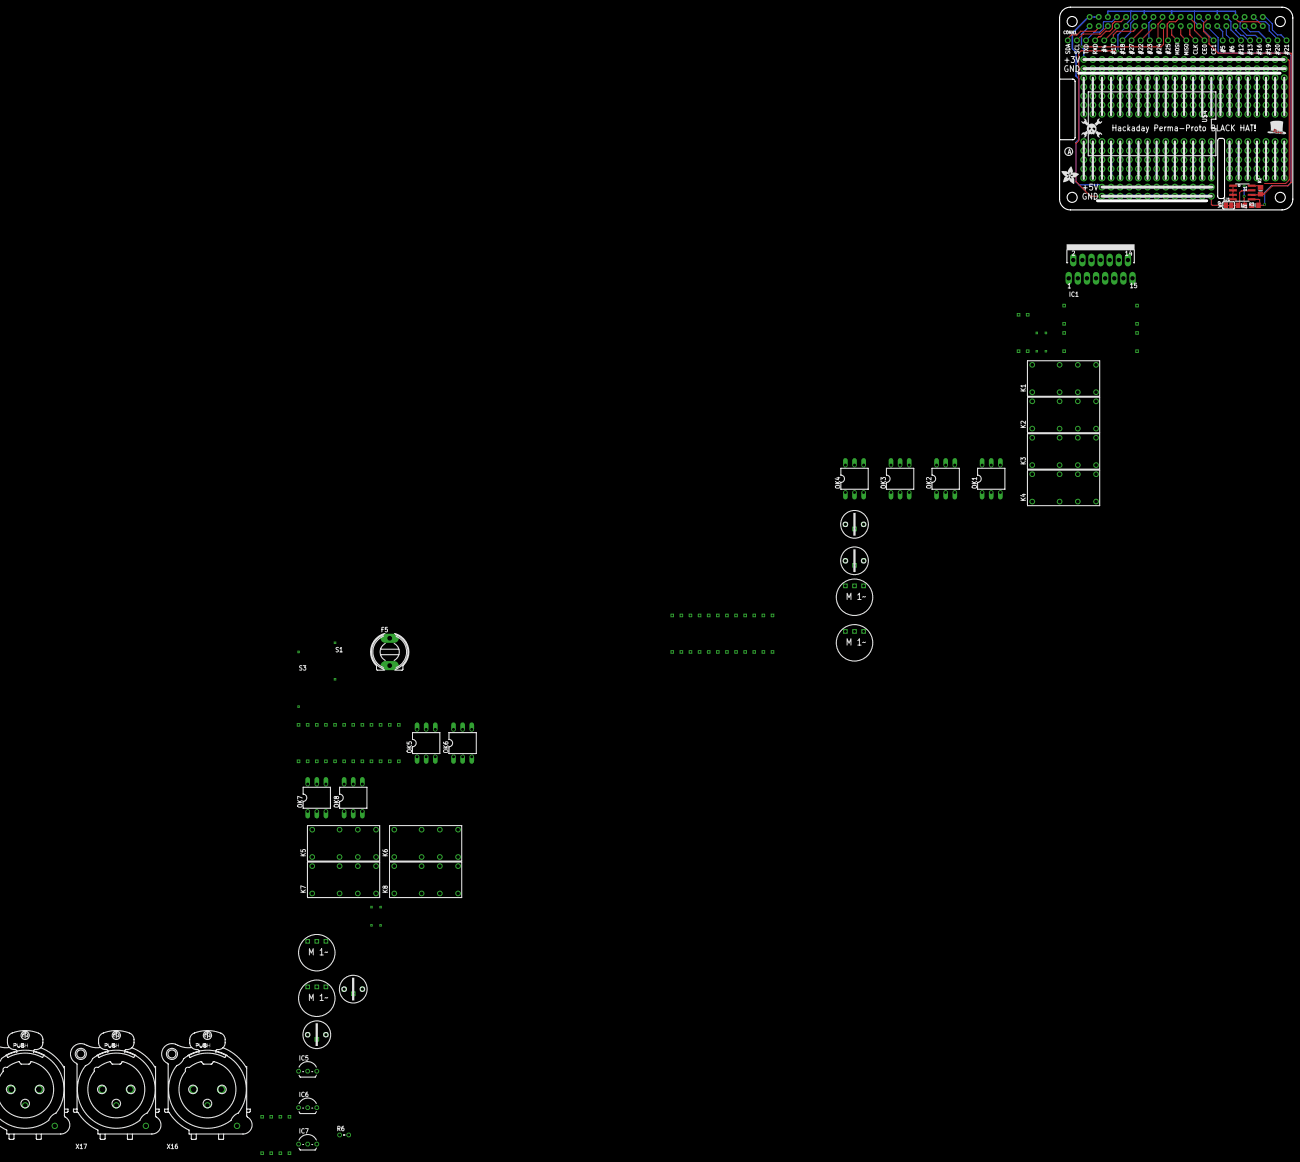
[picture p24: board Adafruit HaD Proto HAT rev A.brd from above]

Board: 2 copper layers, 65.0 x 56.5 mm, 64 parts (0 on the bottom side), 94 nets.

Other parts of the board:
U$1: ADAFRUIT_5MM
U$2: PIHATLOGO
U$3: PCBFEAT-REV-056
U$5: HAD_LOGO_200MIL

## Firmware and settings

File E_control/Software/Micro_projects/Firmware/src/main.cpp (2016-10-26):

#include <Arduino.h>
#include <SimpleModbusSlave.h>
#include <OneWire.h>
#include <DallasTemperature.h>
#include <PID_v1.h> //http://playground.arduino.cc/Code/PIDLibrary
#include <Bounce.h>

#define PWM_1 22
#define PWM_2 23
#define BUZZER 3
#define DO_1 5
#define DO_2 6
#define DO_3 7
#define DO_4 8
#define DO_5 18
#define DO_6 19
#define DO_7 20
#define DO_8 21
#define BUS_PIN 10
#define TEMPERATURE_PRECISION 11
#define ANALOG_RESOLUTION 16

unsigned int REG[100];
double PID_SET_1, PID_IN_1, PID_OUT_1;
double PID_SET_2, PID_IN_2, PID_OUT_2;
//bool STATE;

//elapsedMicros timer;
OneWire ONEWIRE_BUS(BUS_PIN);
DallasTemperature DS18B20(&ONEWIRE_BUS);
DeviceAddress DS18B20_0, DS18B20_1, DS18B20_2;
PID PID1(&PID_IN_1, &PID_OUT_1, &PID_SET_1, 3, 10, 2, DIRECT);
PID PID2(&PID_IN_2, &PID_OUT_2, &PID_SET_2, 3, 10, 2, DIRECT);

void setup()
{
  memset(REG, 0, sizeof(REG));
  modbus_configure(&Serial1, 19200, SERIAL_8N1, 1, 2, sizeof(REG), REG);
  modbus_update_comms(19200, SERIAL_8N1, 1);
  modbus_update();
  REG[60] = 40000;
  REG[61] = 60000;
  REG[64] = 700;
  REG[80] = 1;
  REG[81] = 3;
  REG[82] = 10;
  REG[83] = 1;
  pinMode(DO_1, OUTPUT);
  pinMode(DO_2, OUTPUT);
  pinMode(DO_3, OUTPUT);
  pinMode(DO_4, OUTPUT);
  pinMode(DO_5, OUTPUT);
  pinMode(DO_6, OUTPUT);
  pinMode(DO_7, OUTPUT);
  pinMode(DO_8, OUTPUT);
  pinMode(PWM_1, OUTPUT);
  pinMode(PWM_2, OUTPUT);
  pinMode(BUZZER, OUTPUT);
  digitalWrite(DO_1, !REG[10]);
  digitalWrite(DO_2, !REG[11]);
  digitalWrite(DO_3, !REG[12]);
  digitalWrite(DO_4, !REG[13]);
  digitalWrite(DO_5, !REG[14]);
  digitalWrite(DO_6, !REG[15]);
  digitalWrite(DO_7, !REG[16]);
  digitalWrite(DO_8, !REG[17]);
  analogWriteFrequency(PWM_1, REG[64] );
  analogWriteFrequency(PWM_2, REG[64] );
  analogWriteResolution(ANALOG_RESOLUTION);
  DS18B20.begin();
  DS18B20.getAddress(DS18B20_0, 0);
  DS18B20.getAddress(DS18B20_1, 1);
  DS18B20.getAddress(DS18B20_2, 2);
  DS18B20.setResolution(DS18B20_0, TEMPERATURE_PRECISION);
  DS18B20.setResolution(DS18B20_1, TEMPERATURE_PRECISION);
  DS18B20.setResolution(DS18B20_2, TEMPERATURE_PRECISION);
  PID1.SetOutputLimits(0, 65535);
  PID2.SetOutputLimits(0, 65535);
  PID1.SetMode(AUTOMATIC);
  PID2.SetMode(AUTOMATIC);
  PID1.SetTunings(REG[81], REG[82], REG[83]);
  PID2.SetTunings(REG[81], REG[82], REG[83]);
}

void loop()
{
  modbus_update();
  PID1.Compute();
  PID2.Compute();

  if (REG[80]) {
    if (PID_OUT_1 >= 30000) {
      REG[10]=1;
    }
    if (PID_OUT_1 <= 0) {
      REG[10]=0;
    }
    if (PID_OUT_2 >= 30000) {
      REG[11]=1;
    }
    if (PID_OUT_2 <= 0) {
      REG[11]=0;
    }
    if (REG[10]){
      REG[1] = PID_OUT_1;
    }
    if (REG[11]){
      REG[2] = PID_OUT_2;
    }
  }


  if (REG[64] > 700) {
    REG[64] = 700;
  }
  if (REG[64] < 200) {
    REG[64] = 200;
  }
  PID_IN_1 = REG[41];
  PID_IN_2 = REG[42];
  PID_SET_1 = REG[70];
  PID_SET_2 = REG[71];
  REG[72] = PID_OUT_1;
  REG[73] = PID_OUT_2;

  PID1.SetTunings(REG[81], REG[82], REG[83]);
  PID2.SetTunings(REG[81], REG[82], REG[83]);
  analogWriteFrequency(PWM_1, REG[64] );
  analogWriteFrequency(PWM_2, REG[64] );
  DS18B20.setWaitForConversion(false);
  DS18B20.requestTemperatures();
  REG[40] = DS18B20.getDeviceCount();
  REG[41] = DS18B20.getTempC(DS18B20_0) * 100;
  REG[42] = DS18B20.getTempC(DS18B20_1) * 100;
  REG[43] = DS18B20.getTempC(DS18B20_2) * 100;


  //if ((REG[10])||  (REG[11])){
  //  if (timer>=1000000/REG[65] ) {
  //    timer = 0;
  //    STATE = !STATE;
  //  }
  //}

  // (((VALUE-VAL_MIN)(SET_MAX-SET_MIN))/(VAL_MAX-VAL_MIN)+SET_MIN)
  if (REG[10]){
    //if (timer>=(1000000/REG[65])-((1000000/REG[65])/100)*REG[66]) {
    //if (STATE){
    //analogWrite(PWM_1, REG[60]);
    //} else {
    //analogWrite(PWM_1, REG[61]);
    //}
    //} else {
    analogWrite(PWM_1, ((REG[1]*(REG[61]-REG[60]))/65535)+REG[60]);
    //}
  } else {
    analogWrite(PWM_1, 0);
  }
  if (REG[11]){
    //if (timer>=(1000000/REG[65])-((1000000/REG[65])/100)*REG[66]) {
    //if (STATE){
    //analogWrite(PWM_2, REG[60]);
    //} else {
    //analogWrite(PWM_2, REG[61]);
    //}
    //} else {
    analogWrite(PWM_2,  ((REG[2]*(REG[61]-REG[60]))/65535)+REG[60]);
    //}
  } else {
    analogWrite(PWM_2, 0);
  }
  digitalWrite(DO_1, !REG[10]);
  digitalWrite(DO_2, !REG[11]);
  digitalWrite(DO_3, !REG[12]);
  digitalWrite(DO_4, !REG[13]);
  digitalWrite(DO_5, !REG[14]);
  digitalWrite(DO_6, !REG[15]);
  digitalWrite(DO_7, !REG[16]);
  digitalWrite(DO_8, !REG[17]);
}

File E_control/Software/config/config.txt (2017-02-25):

# For more options and information see
# http://www.raspberrypi.org/documentation/configuration/config-txt.md
# Some settings may impact device functionality. See link above for details

# uncomment if you get no picture on HDMI for a default "safe" mode
#hdmi_safe=1

# uncomment this if your display has a black border of unused pixels visible
# and your display can output without overscan
#disable_overscan=1

# uncomment the following to adjust overscan. Use positive numbers if console
# goes off screen, and negative if there is too much border
#overscan_left=16
#overscan_right=16
#overscan_top=16
#overscan_bottom=16

# uncomment to force a console size. By default it will be display's size minus
# overscan.
#framebuffer_width=1280
#framebuffer_height=720

# uncomment if hdmi display is not detected and composite is being output
#hdmi_force_hotplug=1

# uncomment to force a specific HDMI mode (this will force VGA)
#hdmi_group=1
#hdmi_mode=1

# uncomment to force a HDMI mode rather than DVI. This can make audio work in
# DMT (computer monitor) modes
#hdmi_drive=2

# uncomment to increase signal to HDMI, if you have interference, blanking, or
# no display
#config_hdmi_boost=4

# uncomment for composite PAL
#sdtv_mode=2

#uncomment to overclock the arm. 700 MHz is the default.
#arm_freq=800

# Uncomment some or all of these to enable the optional hardware interfaces
dtparam=i2c_arm=off
#dtparam=i2s=on
dtparam=spi=off

# Uncomment this to enable the lirc-rpi module
#dtoverlay=lirc-rpi

# Additional overlays and parameters are documented /boot/overlays/README

# Enable audio (loads snd_bcm2835)
dtparam=audio=on
dtoverlay=w1-gpio,gpiopin=4,pullup=y
enable_uart=0
gpu_mem=32
disable_splash=1
avoid_warnings=1



# arm_freq=1200
# core_freq=400
# sdram_freq=450
# over_voltage=0
# force_turbo=1
# over_voltage=4
# force_turbo=1


# dtoverlay==w1-gpio-pullup,pullup=1,gpiopin=4

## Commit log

2016-08-16 add eagle files
    [ArduInterface.sch, Arduinomini.sch, Interface.brd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]
2016-08-17 changed board layout
2016-08-17 some edit
    [Teensy3.2_v2_peripherie.brd]
2016-08-17 Update Teensyboard.ino
    added flame upper hysteresis
2016-08-17 added things to layout
    [Teensy3.2_v3_final.brd, Teensy3.2_v3_final.sch]
2016-08-17 adafruit pi hat
    [Adafruit HaD Proto HAT rev A.brd, Adafruit HaD Proto HAT rev A.sch]
2016-08-18 final circuit using rpi
    [Adafruit HaD Proto HAT rev A.brd, Adafruit HaD Proto HAT rev A.sch]
2016-08-19 improve scematic
    [Adafruit HaD Proto HAT rev A.brd, Adafruit HaD Proto HAT rev A.sch]
2016-08-19 modified: Adafruit Hat/Adafruit HaD Proto HAT rev A.brd modified: Adafruit Hat/Adafruit HaD Proto HAT rev A.sch modified: Adafruit Hat/circuit.png modified: Adafruit Hat/eagle.epf
    [Adafruit HaD Proto HAT rev A.brd, Adafruit HaD Proto HAT rev A.sch]
2016-08-20 modified: Arduino/Teensyboard0.3/Teensyboard0.3.ino
2016-09-12 Revert "debuging"
    This reverts commit 3dc7a87a9ffd4770db98203e23c44e083c265fd4.
    # Conflicts:
    # Arduino/Debug/Debug.ino
    # Arduino/Debug/Debug.ino.hex
2016-09-12 Revert "Update Teensyboard0.5.ino"
    This reverts commit 70fae832860cdd7d70b945816dcdc94eb0f86ffe.
2016-09-16 Moved to git
    [Adafruit HaD Proto HAT rev A.brd, Adafruit HaD Proto HAT rev A.sch, ArduInterface.sch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]
2016-09-16 montageplatte cad
    [Montageplatte.FCStd]
2016-10-01 new box design
    [Case.FCStd]

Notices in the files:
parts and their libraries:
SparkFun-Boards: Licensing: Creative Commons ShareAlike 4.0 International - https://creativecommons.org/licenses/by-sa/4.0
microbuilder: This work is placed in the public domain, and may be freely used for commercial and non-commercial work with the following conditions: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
